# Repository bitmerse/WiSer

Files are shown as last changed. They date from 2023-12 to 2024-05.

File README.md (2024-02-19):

# WiSer

Experience seamless wireless serial connectivity with **WiSer**, a powerful set of two devices (**WiSer-USB** and **WiSer-TTL**) designed to facilitate a serial connection between your PC and embedded devices. Say goodbye to cumbersome USB cables and enjoy the freedom of wireless serial communication.



### Connection Diagram
WiSer-Connection

WiSer is a fully **Open Source** project. All hardware design files, firmware source code, and documentation are made available so you can inspect its inner workings. Our goal is to empower users, making it easy to program, understand, customize, and troubleshoot WiSer.

<p align="center">
  
</p>

# :file_folder: Repository contents
  - **/docs** - Documentation resources (Licensed under [CC BY-SA 4.0](docs/LICENSE))
  - **/hw** - Board design files (Licensed under [CERN-OHL-P-2.0](hw/LICENSE))
  - **/src** - Firmware source code (Licensed under [MIT](src/LICENSE))

# :blue_book: Documentation
  - [WiSer Product Page](https://bitmerse.com/products/wiser/)
  - [WiSer Quick Start Guide](https://bitmerse.gitbook.io/wiser-quick-start-guide/)
  - [WiSer Product Manual](https://bitmerse.gitbook.io/wiser-product-manual/)
  - [WiSer Specification](https://bitmerse.gitbook.io/wiser-product-spec-sheet/)

# :shopping_cart: Purchase Options
WiSer is currently available for purchase through the following platform:
 - [Crowd Supply](https://www.crowdsupply.com/bitmerse/wiser)

# :left_speech_bubble: Need Customization?
Do you need assistance customizing WiSer hardware or firmware to integrate into your product? Feel free to reach out to us via email below to explore and take advantage of our commercial services.
- e-mail: [contact@bitmerse.com](mailto:contact@bitmerse.com)
- website: [bitmerse.com](https://www.bitmerse.com)

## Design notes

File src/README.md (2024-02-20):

# WiSer Source Code

This directory contains the WiSer project source code built using the PlatformIO extension in VS Code.

## Compile and Upload

1. Press the "BOOT" button on WiSer-USB/WiSer-TTL and connect it to the USB connector on your computer.
2. After switching to boot mode, the board will accept the new firmware.
3. To build, click on the "Build" button in the PlatformIO toolbar at the bottom of the VS Code window.
4. To upload, click on the "Upload" button in the PlatformIO toolbar at the bottom of the VS Code window.
5. Verify that your code is compiled, uploaded, and executed on the WiSer board.

## Configuration MACROS

1. Before compilation, it is required to change the value of "DEVICE_CONFIG_MODE" to either "DEVICE_CONFIG_MODE_USB" for WiSer-USB or "DEVICE_CONFIG_MODE_UART" for WiSer-UART in `config.h`.
2. change the value of "CONFIG_ESPNOW_BROADCAST_ENABLE" to 1 to enable the brodcast mode in `config.h`. By default, broadcast mode is disabled.
3. change the value of "CONFIG_ESPNOW_ENCRYPTION_ENABLE" to 0 to disable the encryption of data in `config.h`. By default, encyption is enabled in th device.
4. Change the value of "CONFIG_ESPNOW_USE_NVS_PEER_MAC" to 0 in `config.h` to use the default peer MAC address stored in variable "s_app_peer_mac" in `app_espnow.c`. By default, device will use the pre-paired peer MAC address stored in the NVS memory during production.

### Notes

1. By default, WiSer devices are equipped with firmware that includes pre-paired devices, facilitating secure point-to-point wireless serial communication with data encryption enabled. Please be aware that the Broadcast mode is disabled by default.
2. `platformio.ini` contains your project settings. More information about this file can be found [here](https://docs.platformio.org/en/stable/projectconf/index.html).

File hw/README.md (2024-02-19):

# WiSer Hardware

This directory contains the hardware design files for WiSer-USB and WiSer-TTL, created using KiCad EDA.

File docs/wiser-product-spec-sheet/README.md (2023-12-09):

# WiSer

_Seamless plug-and-play solution for wireless serial connections_

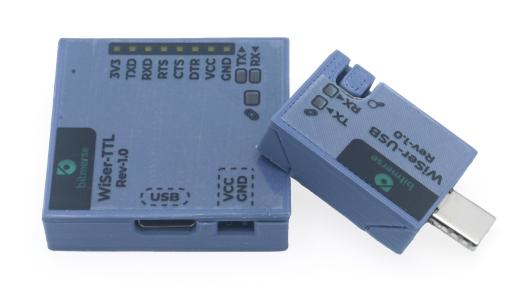
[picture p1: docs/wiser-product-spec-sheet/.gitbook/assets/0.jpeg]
<figure><figcaption></figcaption></figure>

Experience seamless wireless connectivity with WiSer, a device pair featuring WiSer-USB and WiSer-TTL. Simply plug WiSer-USB into your host system and WiSer-TTL into your embedded target device using dedicated UART pins. These devices establish a seamless peer-to-peer wireless connection over a 2.4 GHz Wi-Fi channel, functioning as a wireless serial bridge. Experience effortless communication between your host system and embedded target device over a wireless serial port.

To establish a wireless serial bridge between two host systems, employ a pair of WiSer-USB devices. These devices facilitate the creation of virtual serial ports on each host system, enabling seamless data communication between the host systems via the serial ports.

<table data-header-hidden><thead><tr><th width="327.3333333333333"></th><th width="62"></th><th></th></tr></thead><tbody><tr><td><strong>✔ Reliable</strong></td><td></td><td><strong>✔ Cross-platform</strong></td></tr><tr><td>A reliable solution for wireless connectivity to the serial port of your target device</td><td></td><td>Compatible with host systems running Windows, Linux, or Mac OS and also supports Android phones and tablets</td></tr><tr><td></td><td></td><td></td></tr><tr><td><strong>✔ Simple</strong></td><td></td><td><strong>✔ Open-source</strong></td></tr><tr><td>Plug-and-play convenience with no driver or software installation required</td><td></td><td>The product is entirely open-source, allowing easy modification and tinkering</td></tr></tbody></table>

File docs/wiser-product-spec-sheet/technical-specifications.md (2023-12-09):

# Technical Specifications

| | **WiSer-USB** | **WiSer-TTL** |
| --- | --- | --- |
| **Processing Unit** | Espressif Systems ESP32-S2 Wireless SoC | Espressif Systems ESP32-S2 Wireless SoC |
| **Wireless Protocol** | IEEE 802.11 b/g/n 2.4GHz | IEEE 802.11 b/g/n 2.4GHz |
| **Supported Platforms** | Windows, Linux, Mac and Android | - |
| **Serial Port** | <p><strong>Baud Rate:</strong> All standard and custom rates up to 921,600 baud</p><p><strong>Data bits:</strong> 6-bit, 7-bit, 8-bit</p><p><strong>Parity types:</strong> NONE, ODD, EVEN, MARK, and SPACE</p><p><strong>Stop bits:</strong> 1-bit, 1.5-bit, 2-bit</p><p><strong>Flow control:</strong> software (XON/XOFF), hardware (RTS/CTS), and None</p> | - |
| **User Indication** | 2 red LEDs for RX and TX indication | 3 red LEDs for RX, TX and CONN indication |
| **Buttons** | <p><strong>FIND-PAIR button:</strong> To locate the paired device</p><p><strong>BOOT button:</strong> for FW upgrade</p> | **BOOT button:** for FW upgrade |
| **Connectors** | **USB Type-C male plug:** For power supply, serial data communication and firmware upgrade | <p><strong>USB Type-C Female port:</strong> For Power supply and firmware upgrade</p><p><strong>Power supply Input Pins:</strong> To supply power using Jumper cables</p><p><strong>Serial Interface Pins:</strong></p><ul><li>3V3, TXD, RXD, RTS, CTS, DTR, VCC, GND</li></ul><p>(Note: 3V3 and VCC are power supply output pins which can be used to power external boards)</p> |
| **IO Pin tolerances** | - | <p><strong>Voltage range:</strong> 0 to 3.3V</p><p><strong>Output Pin Current:</strong> 25 mA</p><p><strong>Input Pin Current:</strong> 50nA</p> |
| **Power Supply** | 5V @ 500mA | 5V @ 500mA |
| **Antenna Type** | Omnidirectional chip antenna with 0.5 dBi gain (Peak) | Omnidirectional chip antenna with 0.5 dBi gain (Peak) |
| **Dimensions** | <p><strong>With enclosure:</strong> 37.8 x 20.4 x 8.2 mm</p><p><strong>Without enclosure:</strong> 35.8 x 14.4 x 4.7 mm</p> | <p><strong>With enclosure:</strong> 36.5 x 38.4 x 9.8 mm</p><p><strong>Without enclosure and header pins:</strong> 28 x 29 x 4.3 mm</p> |
| **Weight** | <p><strong>With enclosure:</strong> 4.5 grams</p><p><strong>Without enclosure:</strong> 1.6 grams</p> | <p><strong>With enclosure:</strong> 10.5 grams</p><p><strong>Without enclosure:</strong> 3.7 grams</p> |
| **Operating Temperature** | -40 to 85 °C | -40 to 85 °C |
| **Humidity** | < 60% RH (Non-condensing) | < 60% RH (Non-condensing) |

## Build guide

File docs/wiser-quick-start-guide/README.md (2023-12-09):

# Introduction

Welcome! This quick start guide will help you set up your WiSer devices and get started with wireless serial communication in no time.

WiSer is a hassle-free solution that requires no software installation, no drivers, and no complex setup procedures. WiSer device is supported with Windows 10 or higher, Mac, Linux, and Android OS.

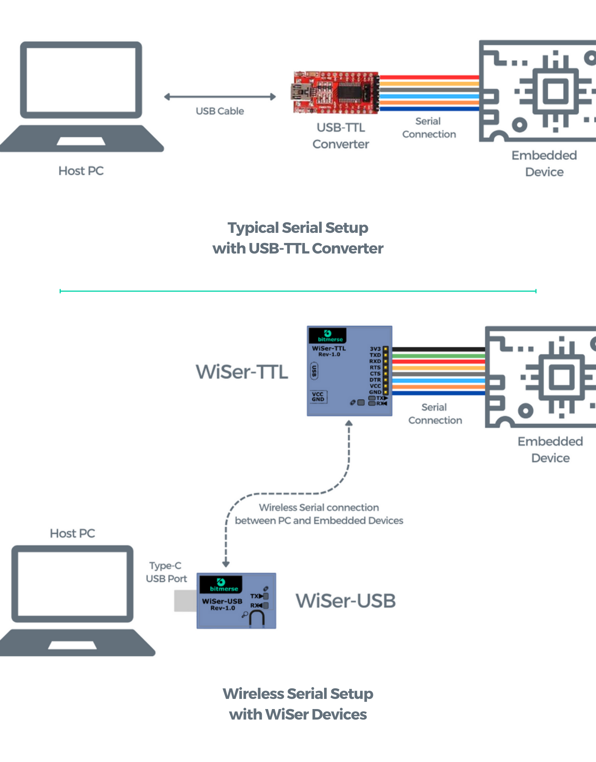
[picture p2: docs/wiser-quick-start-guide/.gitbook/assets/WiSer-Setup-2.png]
<figure><figcaption></figcaption></figure>

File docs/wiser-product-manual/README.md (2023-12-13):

# Introduction

### Introduction to WiSer 

Welcome! This user manual is your guide to setting up and using WiSer, the wireless serial device pair. WiSer provides seamless and hassle-free wireless communication between your PC and embedded devices. WiSer, short for “wireless serial device,” provides a cutting-edge alternative to traditional USB to TTL converters, offering an advanced and efficient means of UART communication.

We understand that connectivity requirements vary, which is why we offer multiple variants of WiSer. For those seeking wireless communication between two systems with only USB ports, our pair of WiSer-USB devices is the ideal solution.

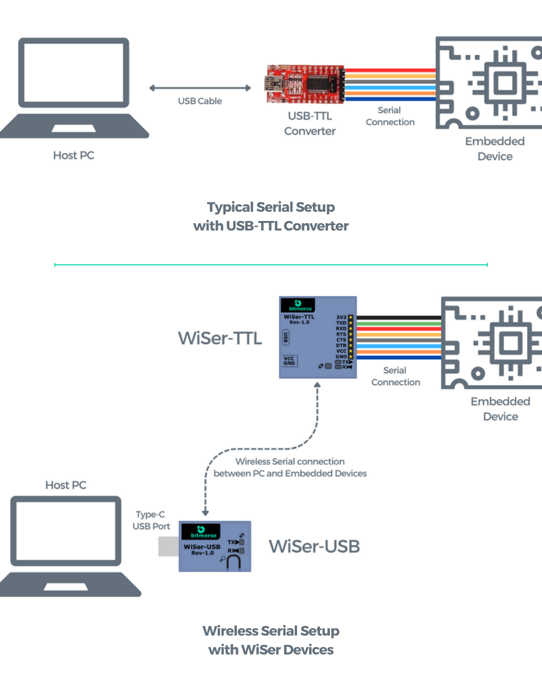
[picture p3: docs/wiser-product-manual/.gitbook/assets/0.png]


### Key Features 

* **Seamless Wireless Connectivity:** WiSer provides a reliable wireless connection, eliminating the limitations of traditional wired setups, and allowing you to move around while maintaining an uninterrupted connection. Connect your PC and embedded devices wirelessly for ultimate convenience.
* **Hassle-Free Setup:** WiSer's plug-and-play nature ensures a quick and effortless setup, saving you time and effort. **WiSer doesn’t require any software or driver installation.**
* **Reliable Cord-Free Serial Communication:** WiSer ensures stable and efficient wireless serial communication for various applications. Say goodbye to tangled cables and enjoy the freedom of wireless connectivity.
* **Secure Data Transfer:** WiSer ensures data protection using AES-CCMP encryption.
* **Complete Electrical Isolation:** WiSer provides full electrical isolation between your embedded device and PC, a distinctive feature absent in conventional USB-TTL converters.
* **Compatibility and Convenience:** Designed to be compatible with a wide range of devices and operating systems, WiSer offers versatility and ease of use.
* **High Performance:** WiSer delivers reliable and fast communication for tasks such as debugging, logging, firmware updates, and data transfer over the serial port.

### List of Potential applications using WiSer 

* **Internet of Things (IoT) Devices:** WiSer enables wireless communication between IoT devices and a PC, facilitating seamless data exchange and control.
* **Robotics/Drones:** WiSer can be utilized in robotic systems/Drones for wireless communication between the central control unit and various robotic components.
* **Embedded Systems:** WiSer simplifies the connection between embedded systems and a PC, allowing for wireless debugging, programming, and data transfer.
* **Home/Industrial Automation:** WiSer can be integrated into automation systems, enabling wireless communication between the central control unit and smart devices or sensors.
* **Automotive Electronics:** WiSer can be employed in automotive applications, allowing wireless communication between the vehicle's onboard systems and external devices for diagnostics, firmware updates, and more.
* **Wearable Devices:** WiSer provides a wireless communication solution for wearable devices, connecting them to a PC for data transfer, configuration, and firmware updates.
* **Electronic Prototyping:** WiSer simplifies the process of prototyping and testing electronic circuits by providing wireless communication between a development board and a PC, reducing the need for physical cables.
* **Remote Monitoring Systems:** WiSer facilitates wireless communication between remote monitoring systems and a central control station, enabling real-time data monitoring and control.
* **Educational Projects:** WiSer can be used in educational settings for teaching and learning about serial communication, embedded systems, and wireless technologies.

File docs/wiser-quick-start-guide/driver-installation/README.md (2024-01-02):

# Driver Installation

### No Drivers Required for WiSer 

WiSer is a hassle-free solution that requires no software installation, no drivers, and no complex setup procedures.

Supported platforms for WiSer device:

* Windows 10 or higher
* Mac
* Linux
* Android

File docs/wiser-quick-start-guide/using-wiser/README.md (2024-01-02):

# Using Wiser

WiSer simplifies the process of establishing wireless serial communication between your PC or device and embedded devices. Here, we'll walk you through the straightforward steps for effectively utilizing WiSer.

### WiSer Devices Connection Setup 

See the [WiSer Setup](../wiser-setup/) section for detailed information about the setup and powering up of the devices.

#### WiSer WS-UT-BM variant

Use this SKU variant for communication between your host system and embedded device as shown in the diagram below.

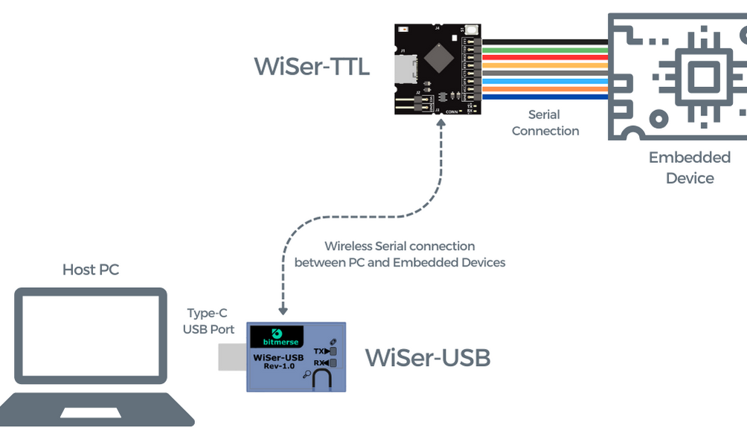
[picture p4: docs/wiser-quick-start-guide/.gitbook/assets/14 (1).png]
<figure><figcaption></figcaption></figure>

#### WiSer WS-UT-EN variant

Use this SKU variant for communication between your host system and embedded device as shown in the diagram below.

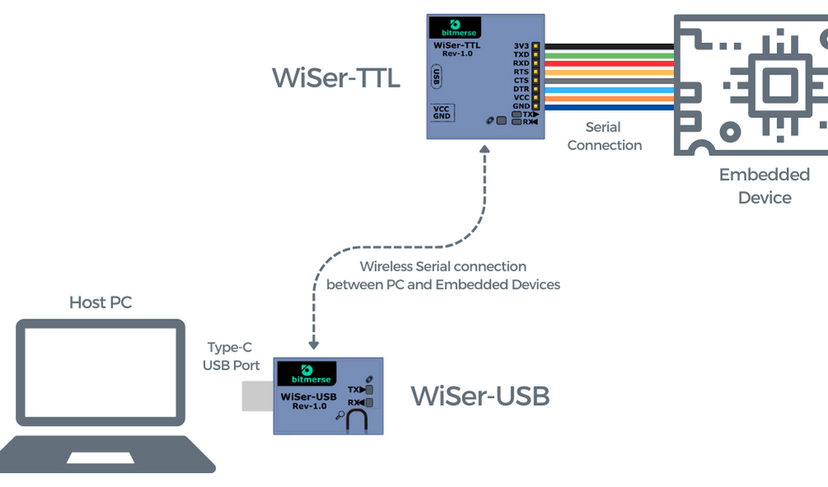
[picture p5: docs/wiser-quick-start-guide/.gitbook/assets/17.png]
<figure><figcaption></figcaption></figure>

#### WiSer WS-UU-EN variant 

Use this SKU variant for communication between 2 host systems as shown in the diagram below.

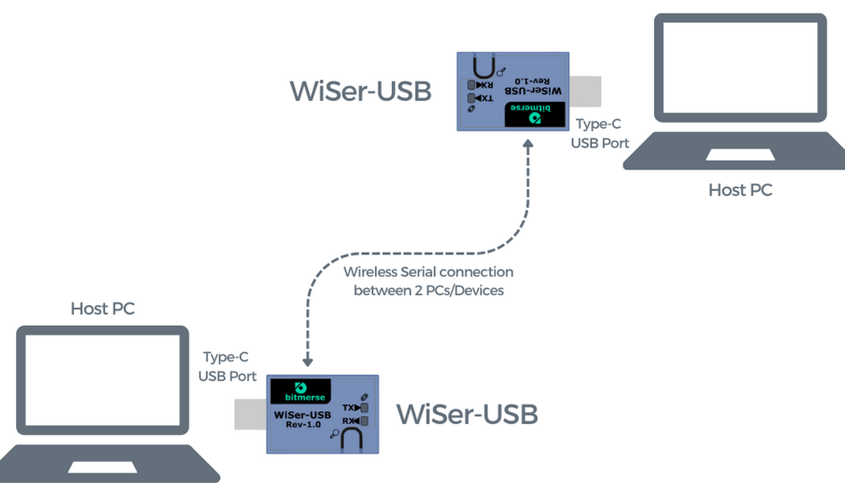
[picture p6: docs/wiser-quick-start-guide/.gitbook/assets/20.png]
<figure><figcaption></figcaption></figure>

### Accessing the Serial Port 

Once the WiSer devices are connected, a virtual serial port will be automatically generated on your PC. Verify serial port in the Device Manager of your PC. You can access it through your preferred terminal software or even any custom software you've developed.

* Following example image shows the WiSer device detected in Device manager of Windows 10 PC

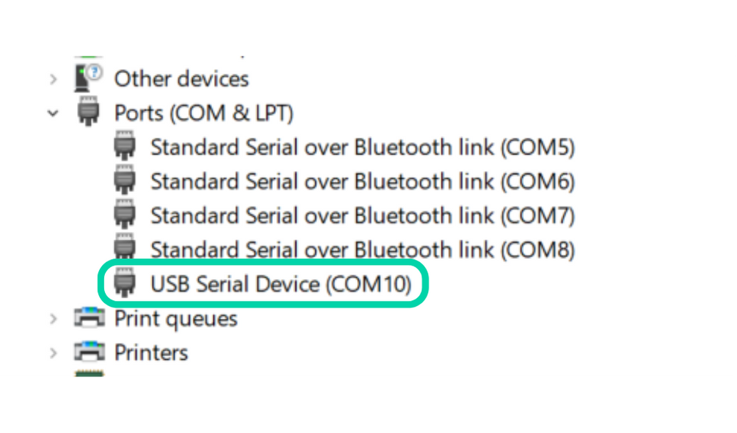
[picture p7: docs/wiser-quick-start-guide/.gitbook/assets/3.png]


* Following example image shows the serial port selection in TeraTerm serial tool.

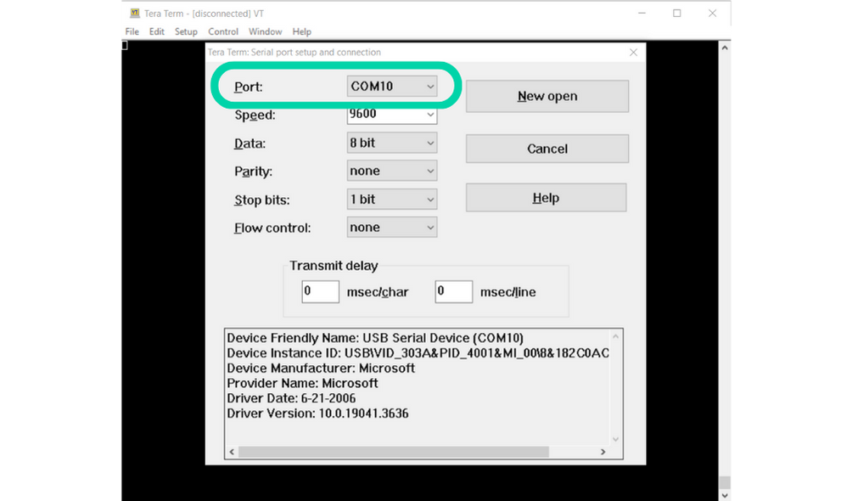
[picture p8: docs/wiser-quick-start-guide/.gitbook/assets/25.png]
<figure><figcaption></figcaption></figure>

### Baud Rate Configuration 

WiSer accommodates various baud rates to meet your communication requirements, whether they are standard or non-standard, with a maximum speed of 921,600 baud. Baud rate configuration can be conveniently adjusted within your terminal software.

By confirming that both the host system and the embedded device share the same baud rate, you can guarantee the successful transmission and reception of data in your wireless serial communication setup.

**Supported baud rates:** all standard and custom rates up to 921,600 baud

* Following example image shows the Baud rate configuration in TeraTerm serial tool.

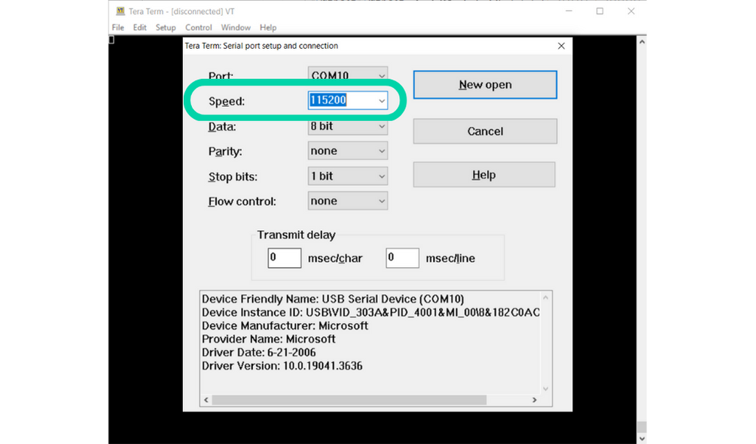
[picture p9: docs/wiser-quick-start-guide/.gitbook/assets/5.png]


### Flow Control Options 

WiSer is equipped with hardware flow control, specifically RTS/CTS, ensuring a dependable data transmission process. To align with your application's requirements, configure your terminal software to integrate flow control. To activate RTS/CTS hardware flow control, press and hold the 'Find Pair' button for more than 2 seconds. This action triggers fast flashing of the CONN LED for 5 seconds, indicating the enabled status. Similarly, a prolonged press on the 'Find Pair' button for more than 2 seconds deactivates the RTS/CTS flow control, signaled by slow flashing of the CONN LED for 5 seconds. It's important to note that flow control is not supported for the WiSer WS-UU-EN variant.

**Supported flow control:** software (XON/XOFF), hardware (RTS/CTS), and None

* Following example image shows the flow control selection in TeraTerm serial tool.

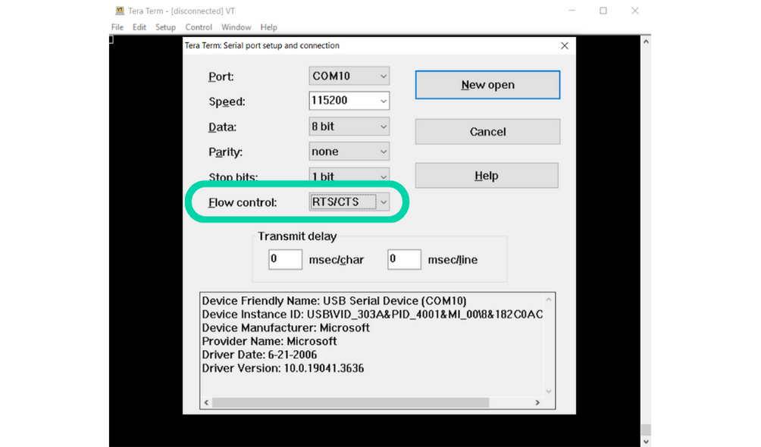
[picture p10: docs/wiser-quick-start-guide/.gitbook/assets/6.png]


### DTR Control Signal 

WiSer also provides the DTR (Data Terminal Ready) control signal, which is crucial for call control in devices like data modems. It signifies that the terminal is prepared for communication. If your target embedded device supports DTR signal, then connect WiSer-TTL’s DTR to your target device and control it using your favorite serial terminal software or custom application. DTR control signal is not supported for WiSer WS-UU-EN variant.

* Following example image shows DTR configuration in Teraterm serial tool.

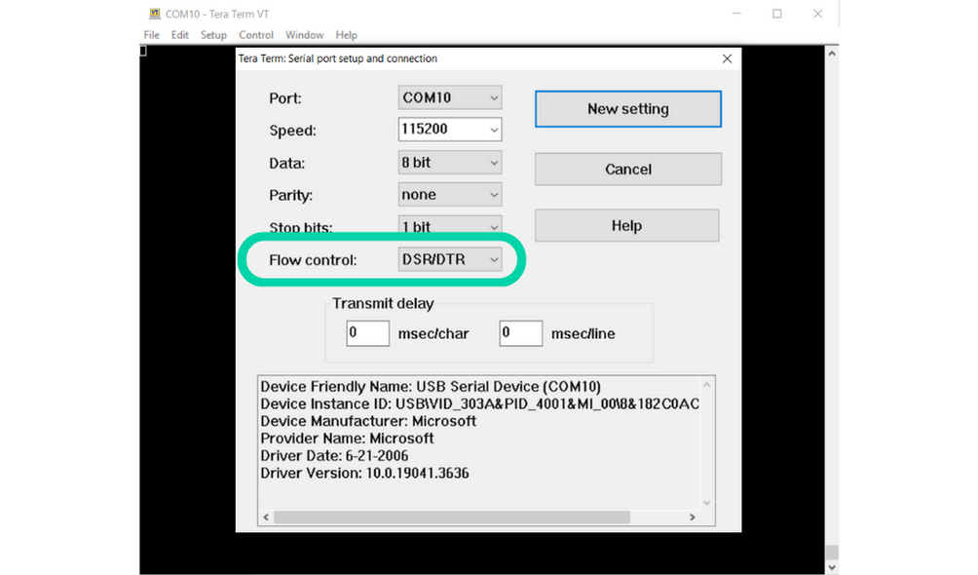
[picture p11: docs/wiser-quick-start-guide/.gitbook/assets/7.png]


### Data bit, Parity, and Stop bits

WiSer provides configuring Data Bit, Parity Type, and Stop Bits settings from your favorite serial terminal software or custom application.

**Supported data bits:** 6-bit, 7-bit, 8-bit

**Supported parity types:** NONE, ODD, EVEN, MARK, and SPACE

**Supported stop bits:** 1-bit, 1.5-bit, 2-bit

* Following example image shows Data Bit, Parity Type, and Stop Bit settings in TeraTerm serial tool.

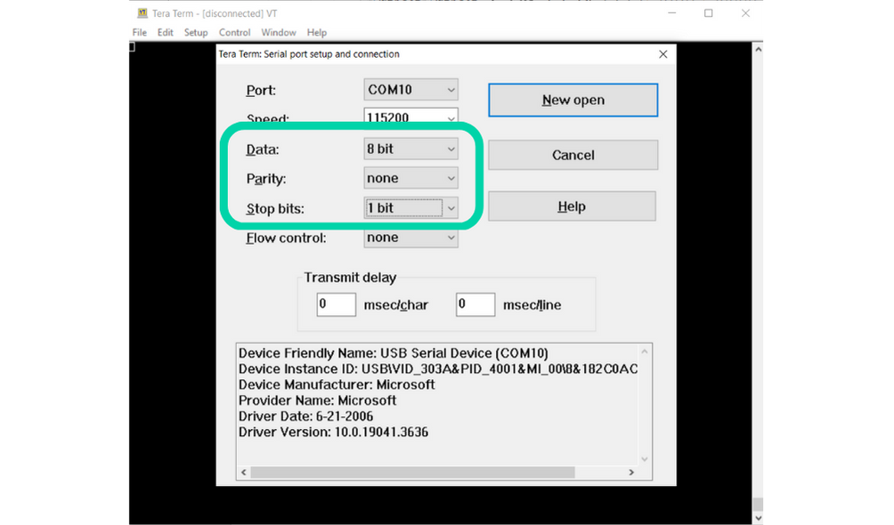
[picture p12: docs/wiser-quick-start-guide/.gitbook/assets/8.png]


### Initiating Serial Communication 

You can now commence serial communication between your PC and the embedded device. For specific communication settings, please consult the user manual of your embedded device.

Ensure that the serial port settings align with those of your target embedded device, then open WiSer's serial port in your favorite serial terminal software or custom application to initiate communication.

* Following example image shows TeraTerm serial port setup window. To open the Serial port, click on “New Open” button.

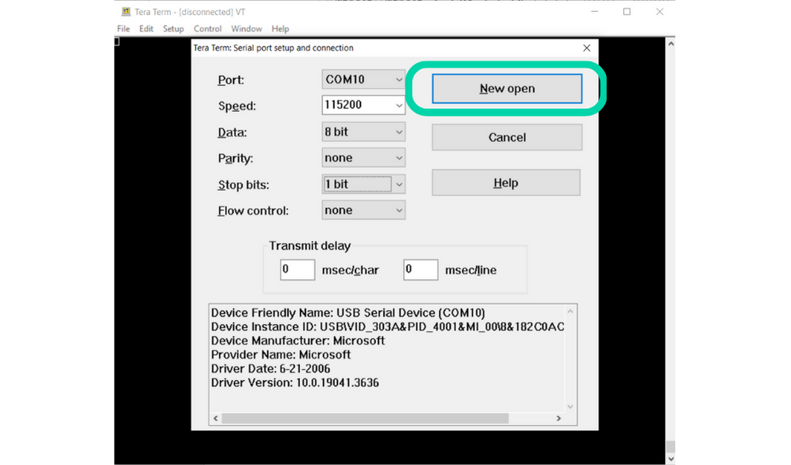
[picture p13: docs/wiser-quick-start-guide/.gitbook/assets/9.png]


* Following example image shows TeraTerm serial terminal with an opened selected serial port and configuration.

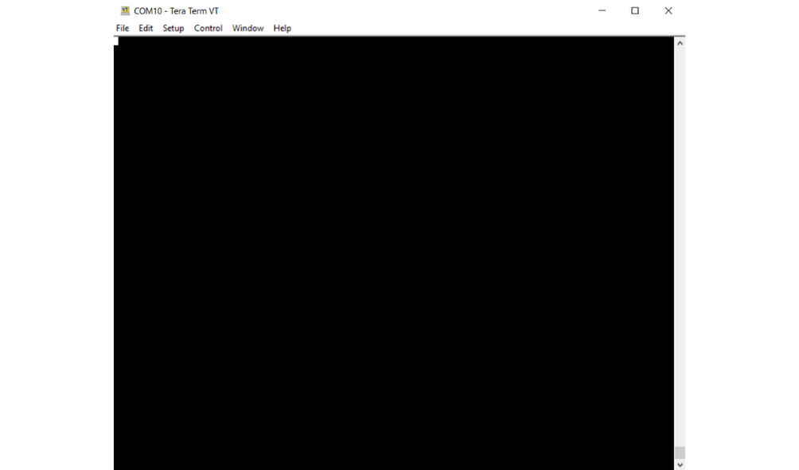
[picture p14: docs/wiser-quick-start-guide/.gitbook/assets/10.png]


#### WiSer WS-UT-BM/EN variant 

* Following image demonstrates the setup of WiSer devices with host system and Raspberry Pi (Embedded Device)

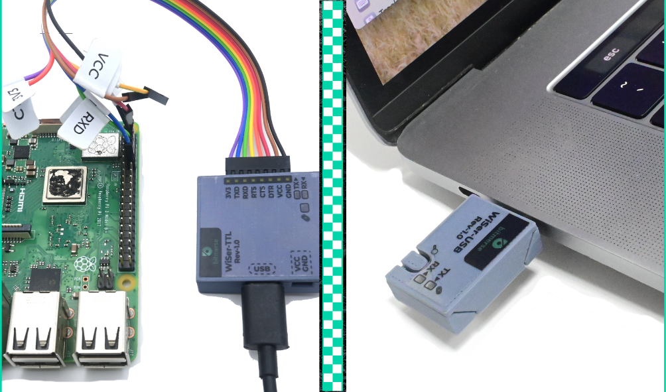
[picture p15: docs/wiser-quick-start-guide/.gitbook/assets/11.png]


* Following image demonstrates the communication between host system and Raspberry PI. It shows wireless access to debug UART terminal of Raspberry PI using WiSer devices.

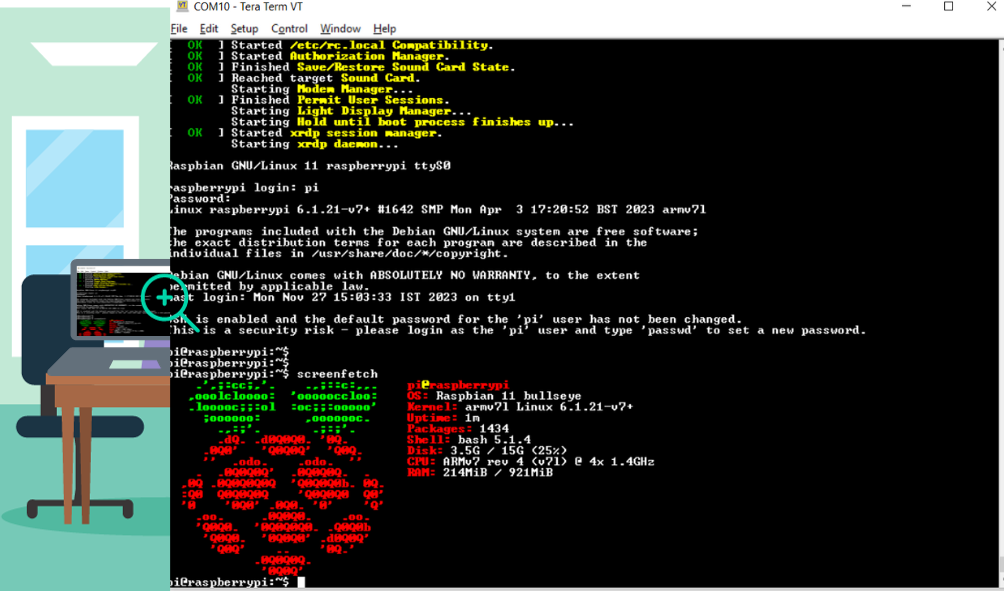
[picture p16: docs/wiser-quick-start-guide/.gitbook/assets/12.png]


* Following image demonstrates the communication between Android Tablet and Raspberry PI. It shows wireless access to debug UART terminal of Raspberry PI on Android device using WiSer devices.

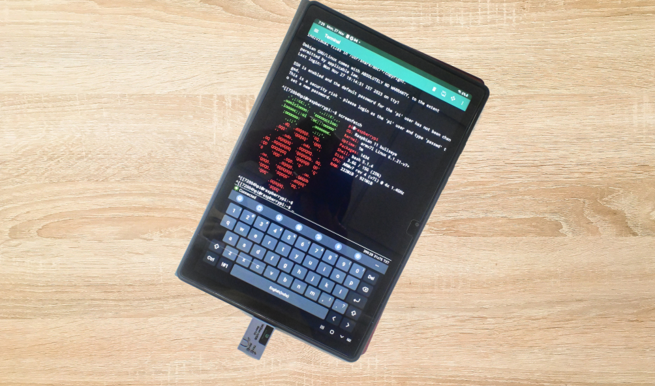
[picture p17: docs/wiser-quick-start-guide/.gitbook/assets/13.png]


#### WiSer WS-UU-EN variant 

* Following image demonstrates 2 host systems communicating wirelessly using WiSer devices. It shows serial terminal of Host PC-1 and Host PC-2.

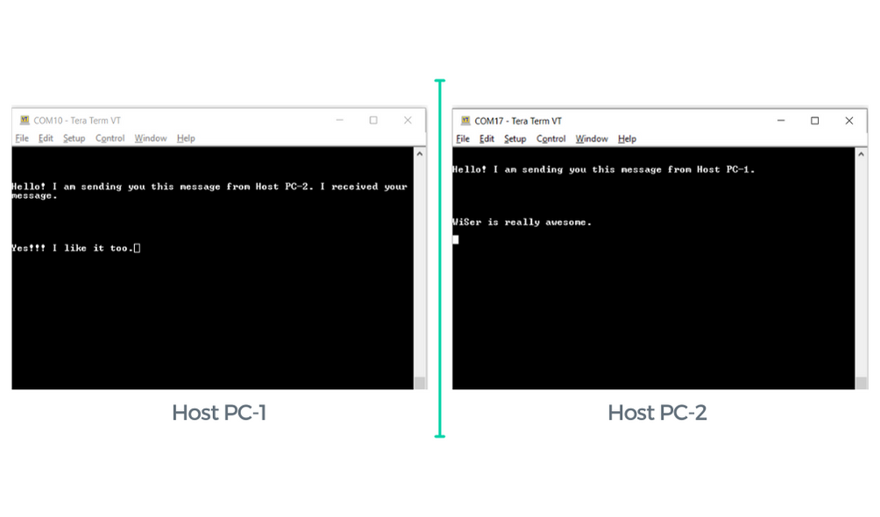
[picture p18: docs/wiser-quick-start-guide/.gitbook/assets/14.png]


By following these steps, you can seamlessly set up and utilize the WiSer device for wireless serial communication. Whether you're working on IoT projects, industrial automation, data logging, or any application that relies on serial communication, WiSer streamlines the process, offering cord-free convenience and efficient data exchange.

For specific instructions on configuring your particular terminal software, please refer to the respective software's user manual.

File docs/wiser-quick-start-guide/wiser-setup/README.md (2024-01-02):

# WiSer Setup

### WiSer Devices connection setup 

#### WS-UT-BM Variant 

**Connecting WiSer-USB**

* Locate the WiSer-USB device in WiSer kit.
* Connect the WiSer-USB device to an available USB port on your PC.

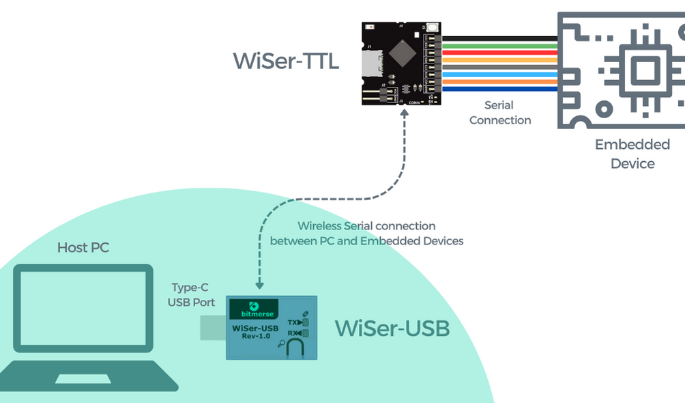
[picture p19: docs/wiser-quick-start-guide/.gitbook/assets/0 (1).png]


**Connecting WiSer-TTL**

* Locate the WiSer-TTL device in WiSer kit.
* Connect the WiSer-TTL device to the serial interface of your embedded device using jumper cable. You also have the flexibility to connect the device to your embedded system using castellated pins positioned at the edge of the board.

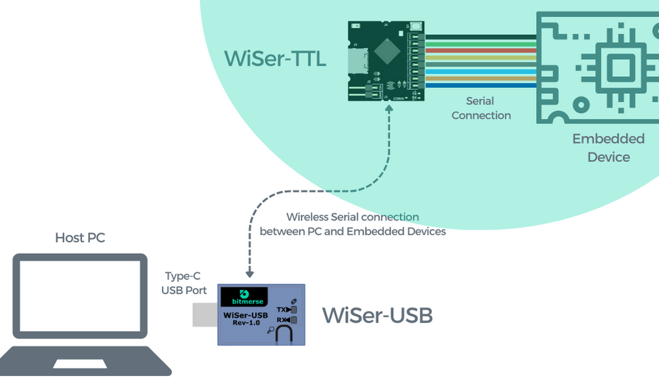
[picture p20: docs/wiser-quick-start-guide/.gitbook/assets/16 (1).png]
<figure><figcaption></figcaption></figure>

#### WS-UT-EN Variant

**Connecting WiSer-USB**

* Locate the WiSer-USB device in WiSer kit.
* Connect the WiSer-USB device to an available USB port on your PC.

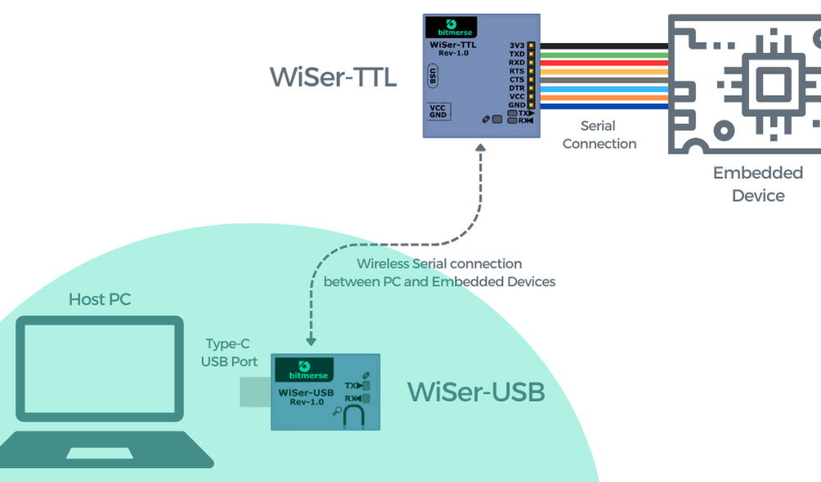
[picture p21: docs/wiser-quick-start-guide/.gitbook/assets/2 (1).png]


**Connecting WiSer-TTL**

* Locate the WiSer-TTL device in WiSer kit.
* Connect the WiSer-TTL device to the serial interface of your embedded device using jumper cable.

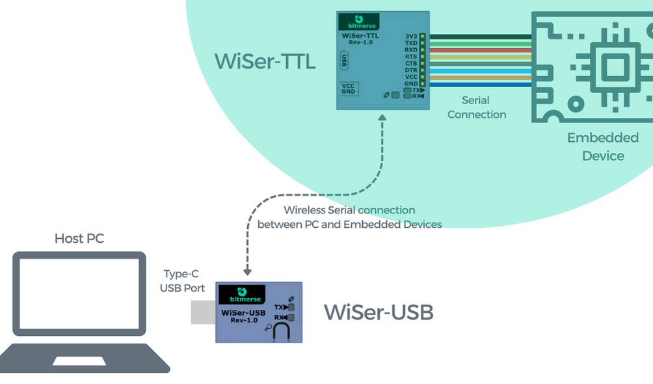
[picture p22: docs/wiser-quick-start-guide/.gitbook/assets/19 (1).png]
<figure><figcaption></figcaption></figure>

#### WS-UU-EN Variant 

**Connecting WiSer-USB**

* Locate the 2 WiSer-USB devices in WiSer kit.
* Connect one WiSer-USB device to an available USB port on your PC/system and another WiSer-USB device to another host system.

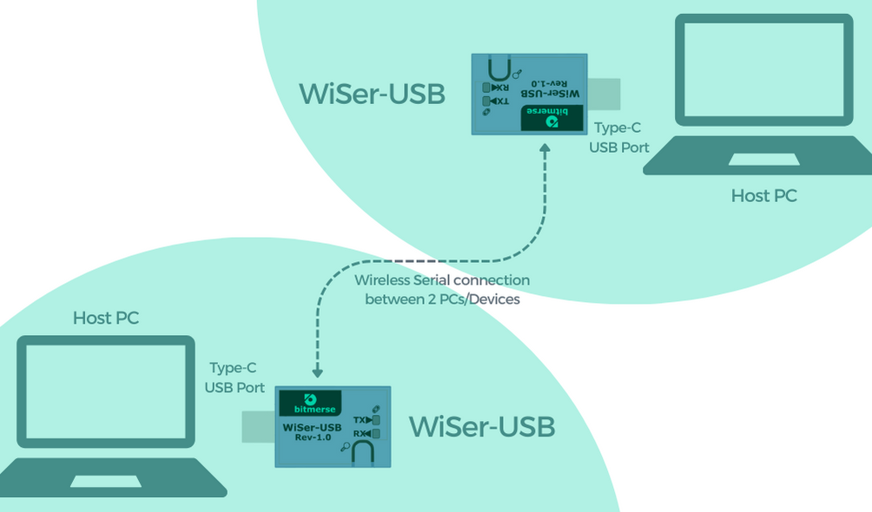
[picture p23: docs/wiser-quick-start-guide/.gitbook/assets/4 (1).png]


### Powering On the Devices 

#### WiSer-USB 

There is only 1 way to provide power to the WiSer-USB board:

* Type-C USB port (Male) plug, default power supply (Directly connects to the Type-C port of host system)

#### WiSer-TTL

There are three mutually exclusive ways to provide power to the WiSer-TTL board:

* Type-C USB port (Female) connector, default power supply (The power can be supplied through a power adapter, power bank, or even from the host system itself)
* Through the header pins (J2), where you can connect to the VCC (+5V) and GND pins.
* Via the castellated pins (J3), where you can provide power by connecting to the VCC (+5V) and GND pins.

This versatility in powering options allows you to choose the method that best suits your setup and project requirements.

### LED Indicators 

WiSer devices are equipped with LED status indicators to convey essential information.

#### Rx and Tx LED 

These LEDs illuminate when active serial communication is established between devices, providing visual confirmation of data transfer.

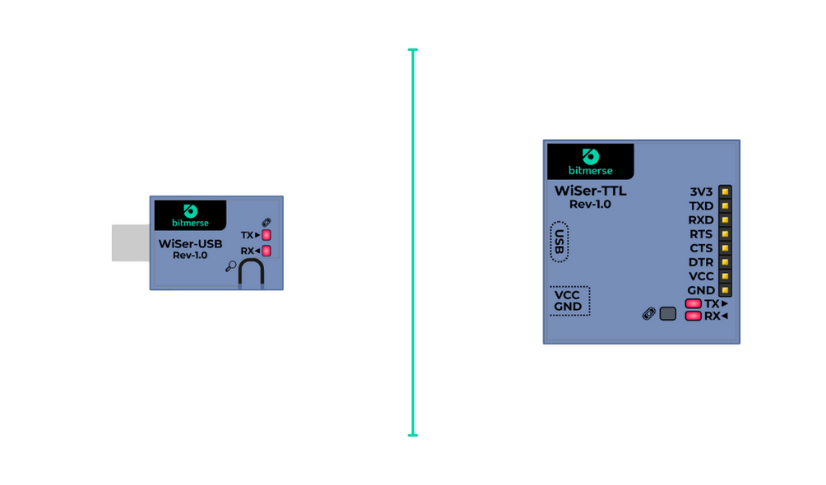
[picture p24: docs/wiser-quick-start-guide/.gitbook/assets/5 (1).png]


#### CONN LED 

This LED activates when you press the 'Find Pair' button on the WiSer-USB device.

**CONN LED Indications:**

* **Steady ON for 5 Seconds:** A short press of the 'Find Pair' button initiates this event. Both paired WiSer devices turn ON the CONN LED for 5 seconds, aiding in identifying the paired device when multiple WiSer device pairs are in use.
* **Flashing FAST for 5 Seconds:** Press and hold the 'Find Pair' button for more than 2 seconds to trigger this event. Both paired devices rapidly flash the CONN LED for 5 seconds, signifying that the RTS/CTS hardware flow control is now enabled. In this mode, the ESP32-S2 chip on WiSer-TTL utilizes the RTS and CTS pins for hardware flow control.
* **Flashing SLOW for 5 Seconds:** Another long press of the 'Find Pair' button for more than 2 seconds triggers this event. Both paired devices slowly flash the CONN LED for 5 seconds, indicating that the RTS/CTS hardware flow control is now disabled. In this mode, the RTS and DTR pins can serve as general-purpose I/Os, controllable via USB requests from the host system.

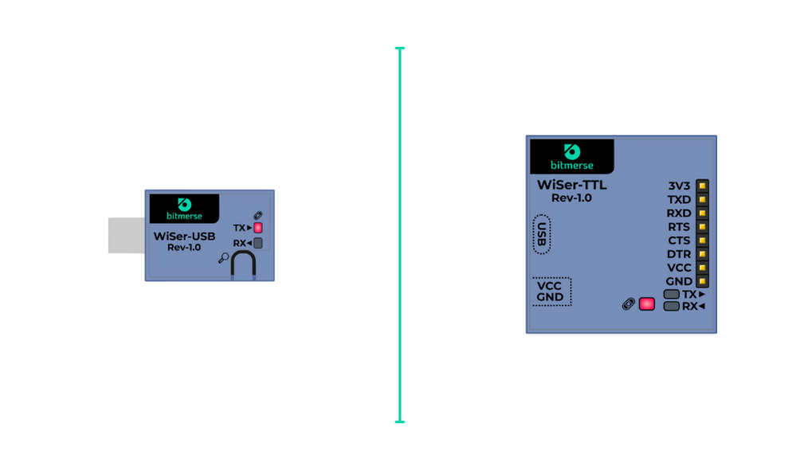
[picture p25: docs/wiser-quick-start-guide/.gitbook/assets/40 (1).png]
<figure><figcaption></figcaption></figure>

These LED indicators serve as your visual guides throughout the setup process, ensuring that you have the necessary feedback to facilitate a seamless connection.

Please note that for the WiSer-USB device, the CONN LED is combined with the Tx (Transmit) LED. This means that when you press ‘Find Pair’ button or transmit data, the same LED will provide feedback for both functions.

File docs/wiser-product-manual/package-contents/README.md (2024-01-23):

# Package Contents

WiSer offers different package variants to suit your specific needs. Please review the table below to understand the package contents for each SKU variant:

| **SKU Variant** | <p><strong>WiSer-USB Device</strong><br><strong>(with Enclosure)</strong></p> | <p><strong>WiSer-TTL Device</strong><br><strong>(without Enclosure)</strong></p> | <p><strong>WiSer-TTL Device</strong><br><strong>(with Enclosure)</strong></p> | **Description** |
| --- | --- | --- | --- | --- |
| **WS-UT-BM** | ✔ | ✔ | | It comes with one WiSer-USB device and one WiSer-TTL device with loose header pins (Not mounted). It's suitable for mounting the WiSer-TTL on your own PCB. |
| **WS-UT-EN** | ✔ | | ✔ | It comes with one WiSer-USB device and one WiSer-TTL device with header pins mounted and also includes Enclosure. It's suitable for connecting the target device using jumper cables. |
| **WS-UU-EN** | ✔ | | | It comes with two WiSer-USB devices. It's suitable for creating a serial port connection between two host systems. |

Select the package variant that best fits your project/product requirements. If you have any questions about the package contents or need assistance, please feel free to [reach out to our customer support team.](mailto:support@bitmerse.com)

### What's Included 

Your selected WiSer SKU Variant includes the following components:

#### WS-UT-BM Variant 

* WiSer-USB Device with Enclosure
* WiSer-TTL Device
* USB Power Cable for WiSer-TTL
* loose header pins (Not mounted)
* Jumper Cables
* Quick Start Guide

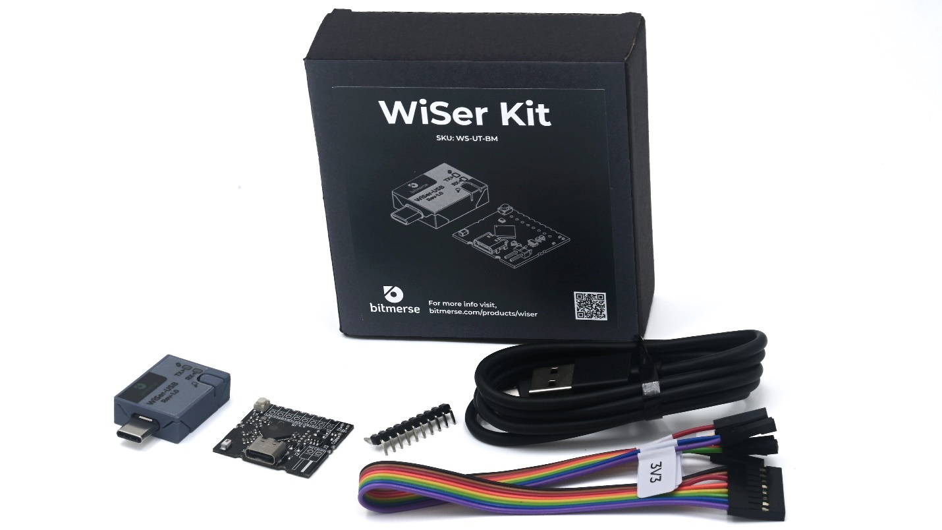
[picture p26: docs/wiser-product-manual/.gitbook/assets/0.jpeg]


#### WS-UT-EN Variant 

* WiSer-USB Device with Enclosure
* WiSer-TTL Device with Enclosure (with header pins mounted)
* USB Power Cable for WiSer-TTL
* Jumper Cables
* Quick Start Guide

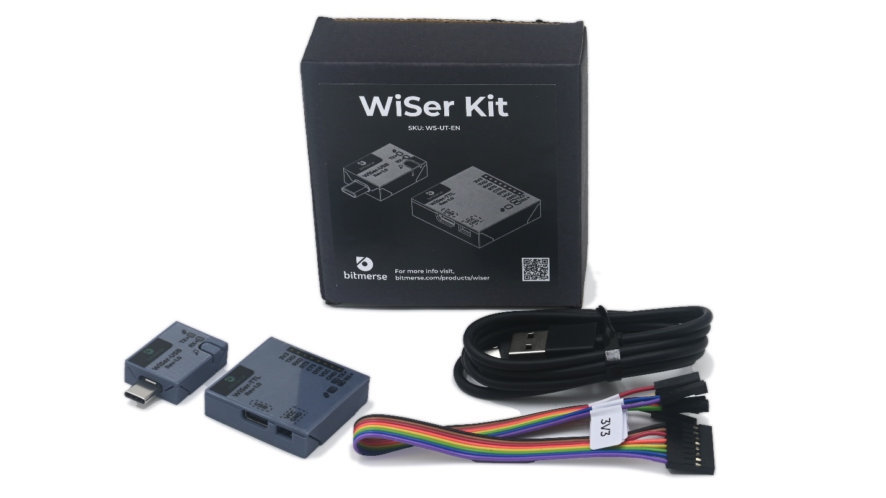
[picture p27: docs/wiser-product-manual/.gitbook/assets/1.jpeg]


#### WS-UU-EN Variant 

* 2 WiSer-USB Devices with Enclosure
* Quick Start Guide

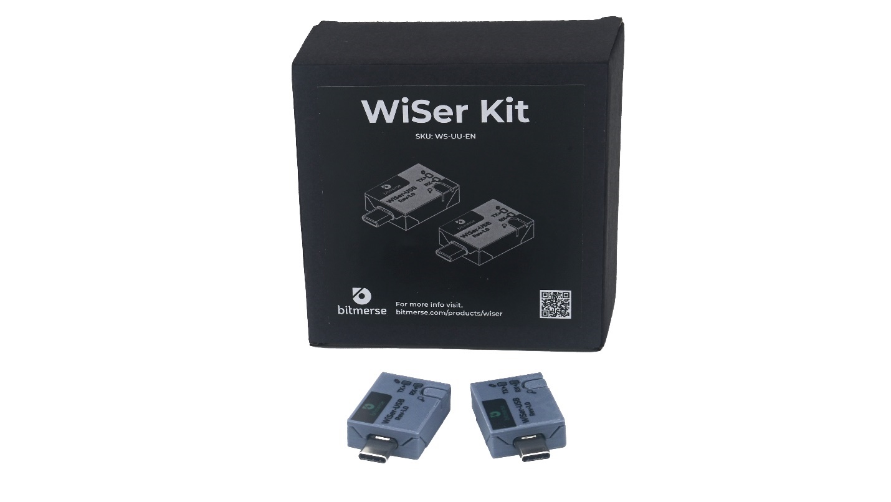
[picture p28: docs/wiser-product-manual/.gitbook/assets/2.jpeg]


Ensure that all items are present in your package before proceeding.

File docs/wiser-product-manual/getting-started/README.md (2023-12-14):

# Getting Started

### Device Overview 

Before setting up WiSer, let's familiarize ourselves with the devices:

#### WiSer-USB 

**Functional Description**

This device connects to your PC/System. Upon powering up, the WiSer-USB creates a virtual serial port on the host system and waits for its paired WiSer device to power up as well.

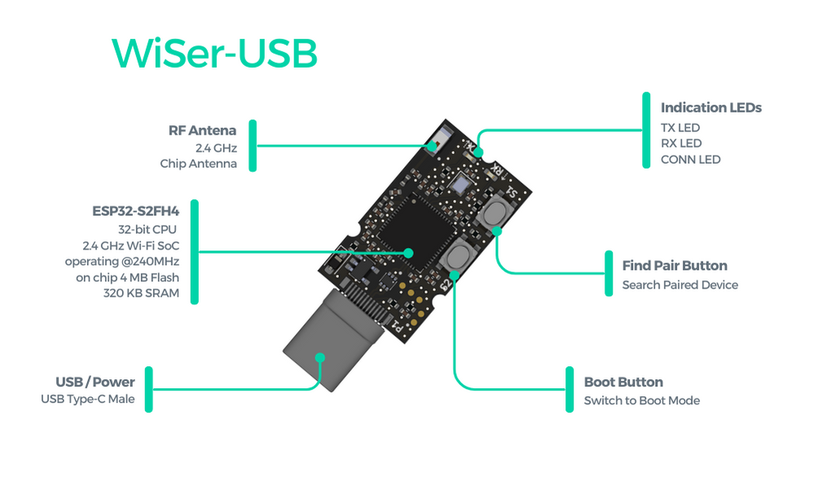
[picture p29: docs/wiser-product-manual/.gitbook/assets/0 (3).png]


The WiSer-USB device is factory-paired with either a WiSer-TTL or another WiSer-USB device, depending on the product variant (as indicated in SKU Variant Table). Once both the WiSer-USB and the paired device are powered up, they automatically establish a connection.

The **‘Find Pair'** button on WiSer serves a multi-functional role, facilitating the identification and configuration of paired devices:

1. **Short Press:** Initiates the identification event. When you briefly press the 'Find Pair' button, the CONN LED on both paired WiSer devices remains steadily ON for 5 seconds. This helps users identify the specific paired devices, particularly useful when managing multiple WiSer device pairs.
2. **Long Press (More than 2 Seconds):**

* **Flashing FAST:** A prolonged press triggers the RTS/CTS hardware flow control activation. Both paired devices respond by rapidly flashing the CONN LED for 5 seconds, indicating that the hardware flow control is now enabled. In this mode, the ESP32-S2 chip on WiSer-TTL utilizes the RTS and CTS pins for hardware flow control.
* **Flashing SLOW:** Another long press deactivates the RTS/CTS hardware flow control. In response, both paired devices exhibit a slow flash of the CONN LED for 5 seconds, signaling that the hardware flow control is now disabled. In this mode, the RTS and DTR pins can serve as general-purpose I/Os, controllable via USB requests from the host system.

In summary, the 'Find Pair' button provides a convenient way to manage and identify paired WiSer devices, as well as to toggle the RTS/CTS hardware flow control functionality based on the duration of the button press. Upon initial power-up, the WiSer device has **hardware flow control deactivated by default.**

The **‘Boot button’** serves the purpose of flashing firmware on the ESP32-S2 chip within the WiSer-USB device.

Once the connection is established, users can engage in serial communication by using applications such as PuTTY, TeraTerm, or any other software that operates through a serial port.

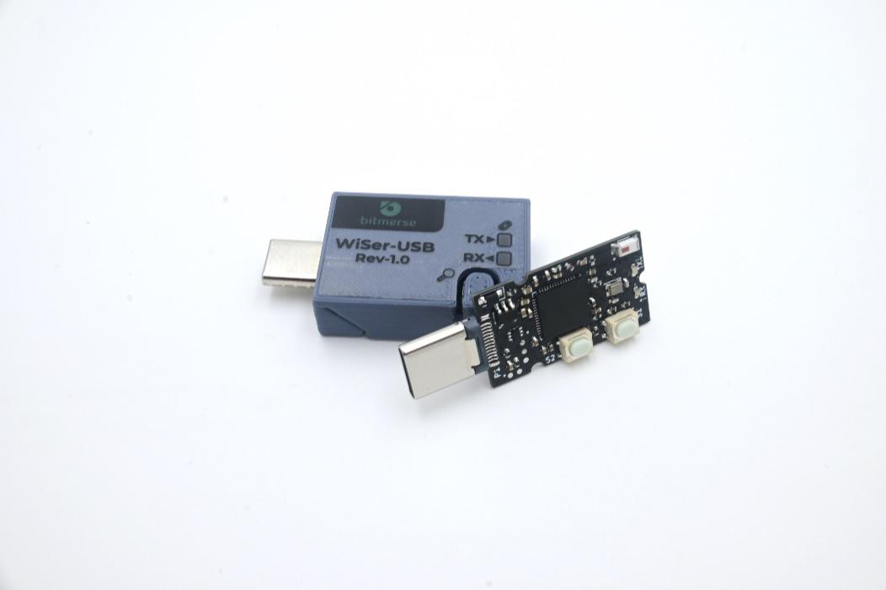
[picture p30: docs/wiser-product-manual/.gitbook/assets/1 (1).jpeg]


Notably, the WiSer-USB device supports a wide range of baud rates, whether standard or non-standard, with a maximum speed of 921,600 baud. Any changes to the baud rate in your application will be automatically synchronized with the paired device.

| **Key Component** | **Description** |
| --- | --- |
| ESP32-S2FH4 | A MCU with ESP32-S2 at its core. For more information, see [ESP32-S2 Datasheet](https://www.espressif.com/sites/default/files/documentation/esp32-s2\_datasheet\_en.pdf). |
| S1 | Find Pair button. Short press the button to identify the paired WiSer-USB or WiSer-TTL device. Long press the button for 2 seconds to toggle the RTS/CTS hardware flow control. |
| S2 | Boot button. Holding down the button and power on the board to switch into boot mode and flash new firmware. Note: Flashing new firmware will erase the WiSer firmware. |
| P1 | Type-C USB Port (Male) plug. Power supply for the board as well as the communication interface between a computer and the ESP32-S2 MCU. |
| TX/CONN LED | Reflects the transmit data on serial interface. Turns ON for 5 seconds when user presses the ‘Find Pair’ button for more than 1 second. |
| RX LED | Reflects the received data on serial interface. |

**Power Supply Options**

There is only 1 way to provide power to the WiSer-USB board:

* Type-C USB port (Male) plug, default power supply (Directly connects to the Type-C port of host system)

#### WiSer-TTL 

**Functional Description**

The WiSer-TTL device connects to your embedded device for wireless communication. Upon power-up, the WiSer-TTL will establish a connection with its paired WiSer-USB device.

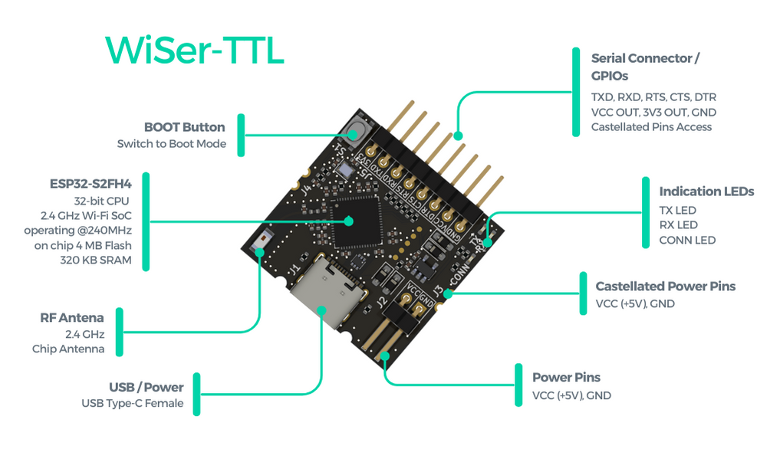
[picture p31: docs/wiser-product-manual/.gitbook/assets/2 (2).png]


The **‘Boot button’** serves the purpose of flashing firmware on the ESP32-S2 chip within the WiSer-TTL device.

The WiSer-TTL device is available in different variants. You can choose between variant with header pins pre-mounted or variant with loose header pins. This flexibility allows you to select the option that best suits your project requirements.

If you opt for the variant with header pins pre-mounted, you can effortlessly connect the WiSer-TTL device to your target device using jumper cables. On the other hand, if you choose the variant without header pins, you have the flexibility to solder it directly onto your embedded device's PCB, ensuring a secure and integrated connection. This adaptability allows you to tailor the setup to your specific project requirements, making the WiSer-TTL device a versatile choice for various applications.

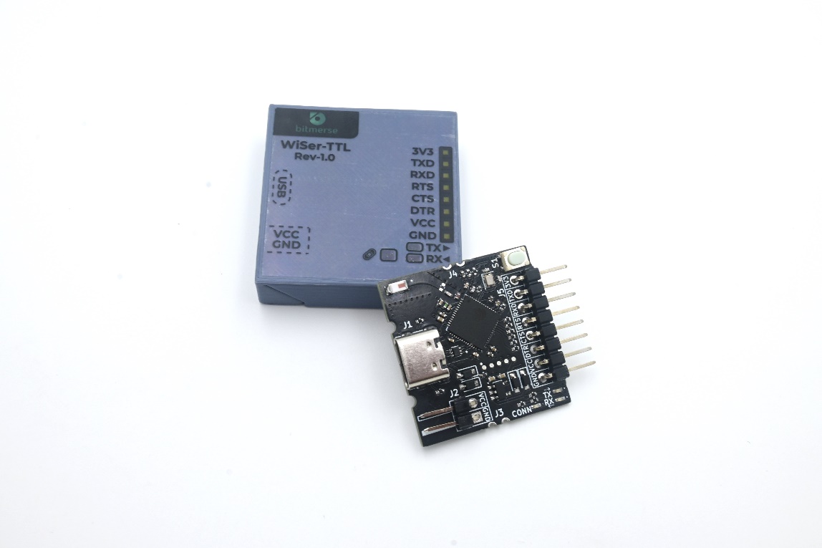
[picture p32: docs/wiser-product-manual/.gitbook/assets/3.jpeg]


You can use WiSer-TTL as ESP32-S2 development board as well and you can even integrate this small-sized board easily with PCB of your product.

| **Key Component** | **Description** |
| --- | --- |
| ESP32-S2FH4 | A MCU with ESP32-S2 at its core. For more information, see [ESP32-S2 Datasheet](https://www.espressif.com/sites/default/files/documentation/esp32-s2\_datasheet\_en.pdf). |
| S1 | Boot button. Holding down the button and power on the board to switch into boot mode and flash new firmware. Note: Flashing new firmware will erase the WiSer firmware. |
| J1 | Type-C USB Port (Female) connector. Power supply for the board as well as the communication interface between a computer and the ESP32-S2 MCU. |
| J2 | Header pins for power supply. VCC (+5V) and GND. |
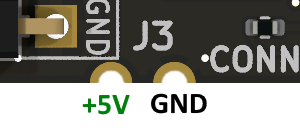
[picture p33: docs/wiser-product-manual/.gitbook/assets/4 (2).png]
| J3 | <p>The castellated Power pins.</p> |
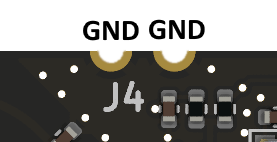
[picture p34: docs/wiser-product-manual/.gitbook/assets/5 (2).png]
| J4 | <p>The castellated Ground pins.</p> |
| TX LED | Reflects the transmit data on serial interface. |
| RX LED | Reflects the received data on serial interface. |
| CONN LED | Turns ON for 5 seconds when user presses the ‘Find Pair’ button for more than 1 second. |
| <p>I/O Header pins<br>(J5)</p> | The pins of ESP32-S2 MCU required for serial interface are broken out to the pin header on the board. |

**Header Block**

The table below provides the Name and Function of I/O header pins on connector J5 on the WiSer-TTL board.

| **No.** | **Name** | **GPIO** | **Function** |
| --- | --- | --- | --- |
| 1 | GND | - | Ground. |
| 2 | VCC | - | +5V output pin. |
| 3 | DTR | GPIO34 | UART DTR pin. (3.3V tolerant I/O) |
| 4 | CTS | GPIO35 | <p>UART CTS pin. (3.3V tolerant I/O)</p><p>Connect this pin to target device only if the RTS/CTS hardware flow control is enabled on target device.</p><p><strong>Note:</strong> Keep this pin NC (not connected) if hardware RTS/CTS hardware flow controller is disabled on target device.</p> |
| 5 | RTS | GPIO36 | <p>UART RTS pin. (3.3V tolerant I/O)</p><p>Connect this pin to target device only if the RTS/CTS hardware flow control is enabled on target device.</p><p><strong>Note:</strong> Keep this pin NC (not connected) if hardware RTS/CTS hardware flow controller is disabled on target device.</p> |
| 6 | RXD | GPIO37 | UART RX pin (3.3V tolerant I/O) |
| 7 | TXD | GPIO38 | UART TX pin (3.3V tolerant I/O) |
| 8 | 3V3 | - | +3.3V output pin |

**Power Supply Options**

There are three mutually exclusive ways to provide power to the WiSer-TTL board:

* Type-C USB port (Female) connector, default power supply (The power can be supplied through a power adapter, power bank, or even from the host system itself)
* Through the header pins (J2), where you can connect to the VCC (+5V) and GND pins.
* Via the castellated pins (J3), where you can establish power by connecting to the VCC (+5V) and GND pins.

### System Requirements 

#### WS-UT-BM/EN Variant 

To use WiSer WS-UT-BM/EN, you'll need:

* A PC/Device with a USB port (Windows 10 or higher / Mac / Linux / Android OS)
* An embedded device with a compatible serial interface

#### WS-UT-BM/EN Variant 

To use WiSer WS-UU-EN, you'll need:

* 2 PCs/Devices with a USB port (Windows 10 or higher / Mac / Linux / Android OS)

Please check the specific requirements for your embedded device in the user manual of the respective device.

### Safety Precautions 

* Avoid exposure to extreme temperatures and humidity.
* Handle WiSer devices with care, avoiding impact and physical damage.
* Keep WiSer devices away from liquids and moisture.

Please ensure that you follow safety guidelines while using WiSer devices.

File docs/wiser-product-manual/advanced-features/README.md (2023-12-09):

# Advanced Features

### Firmware Updates 

Both WiSer devices feature the ability to update their firmware through a USB connection, facilitated by the dedicated boot button on the device, allowing for a seamless transition into bootloader mode. WiSer devices may receive firmware updates to enhance performance and add new features. Check our website for firmware updates and follow the provided instructions to update your devices.

### Independent ESP32-S2 Dev Boards 

In addition to their primary function as WiSer devices for wireless serial communication, both WiSer-USB and WiSer-TTL possess advanced capabilities. You can use them as independent ESP32-S2 development boards for your personal projects. You can also integrate these small-sized boards into your product’s board easily.

**Note:** Once you overwrite the firmware in WiSer devices, they will no longer function as WiSer devices for wireless serial communication.

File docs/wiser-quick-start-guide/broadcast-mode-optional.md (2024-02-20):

# Broadcast Mode (Optional)

### **Enable Broadcast Mode (Optional)**

If you have multiple WiSer-enabled devices and want to establish wireless serial communication between them without physical cables, you can enable the Broadcast Mode. This mode allows seamless serial communication between multiple devices in your environment.

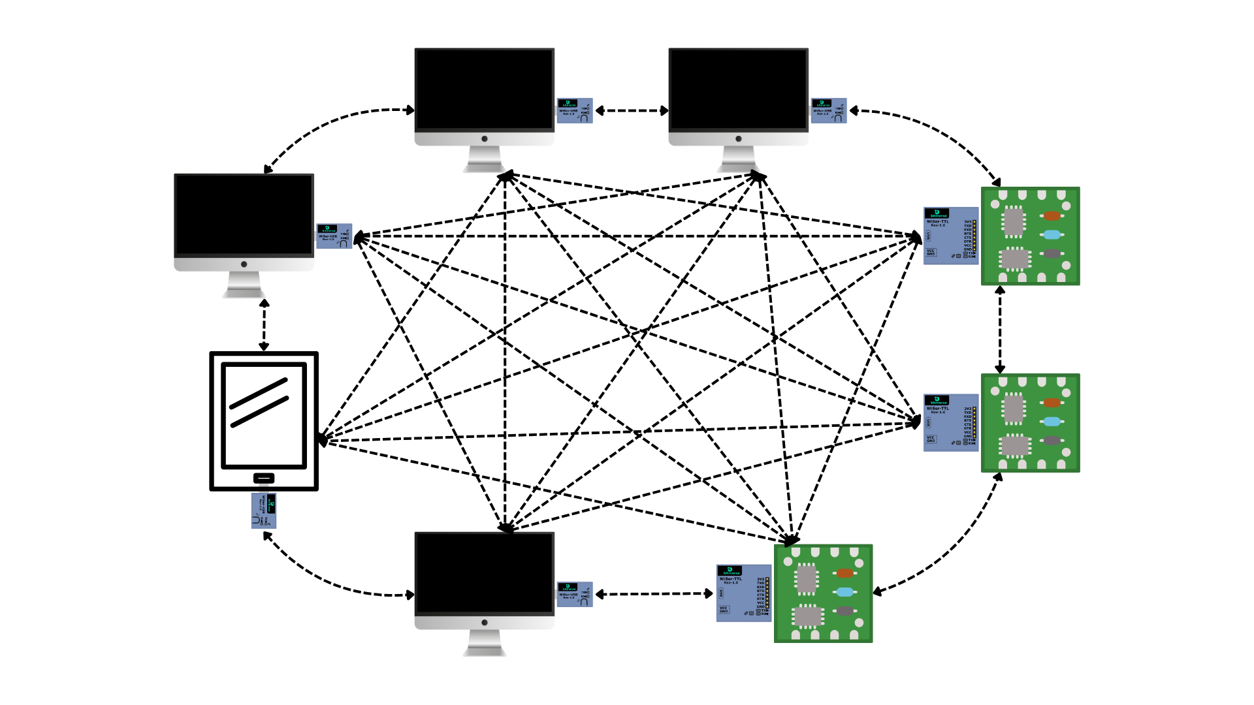
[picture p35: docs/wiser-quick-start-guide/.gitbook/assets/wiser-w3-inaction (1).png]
<figure><figcaption></figcaption></figure>

#### **How to Enable**

* To enable the broadcast mode in WiSer devices, read the firmware's [README.md](../../src/) file.&#x20;

#### **Using Broadcast Mode**

* Once enabled, each host system or embedded device connected to a WiSer-USB or WiSer-TTL device gains the ability to broadcast data to all other connected devices.

**Note:**&#x20;

* Enabling Broadcast mode disables internal encryption in WiSer devices. But, you can always add encryption and device filtration in your application code.
* By default, WiSer devices are equipped with firmware that includes pre-paired devices, facilitating secure point-to-point wireless serial communication with data encryption enabled. Please be aware that the Broadcast mode is disabled by default.

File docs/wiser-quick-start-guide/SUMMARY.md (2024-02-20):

# Table of contents

* [Introduction](README.md)
* [Package Contents](package-contents.md)
* [WiSer Setup](wiser-setup/README.md)
  * [WiSer Devices connection setup](wiser-setup/README.md#\_toc150171902)
  * [Powering On the Devices](wiser-setup/README.md#\_toc150171905)
  * [LED Indicators](wiser-setup/README.md#\_toc150171908)
* [Driver Installation](driver-installation/README.md)
  * [No Drivers Required for WiSer](driver-installation/README.md#\_toc150171912)
* [Using Wiser](using-wiser/README.md)
  * [WiSer Devices Connection Setup](using-wiser/README.md#\_toc150171914)
  * [Accessing the Serial Port](using-wiser/README.md#\_toc150171916)
  * [Baud Rate Configuration](using-wiser/README.md#\_toc150171917)
  * [Flow Control Options](using-wiser/README.md#\_toc150171918)
  * [DTR Control Signal](using-wiser/README.md#\_toc150171919)
  * [Data bit, Parity and Stop bits](using-wiser/README.md#data-bit-parity-and-stop-bits)
  * [Initiating Serial Communication](using-wiser/README.md#\_toc150171920)
* [Broadcast Mode (Optional)](broadcast-mode-optional.md)
* [Troubleshooting](troubleshooting.md)

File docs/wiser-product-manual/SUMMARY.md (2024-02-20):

# Table of contents

* [Introduction](README.md)
  * [Introduction to WiSer](README.md#\_toc150171884)
  * [Key Features](README.md#\_toc150171885)
  * [List of Potential applications using WiSer](README.md#\_toc150171886)
* [Package Contents](package-contents/README.md)
  * [What's Included](package-contents/README.md#\_toc150171888)
* [Getting Started](getting-started/README.md)
  * [Device Overview](getting-started/README.md#\_toc150171894)
  * [System Requirements](getting-started/README.md#\_toc150171897)
  * [Safety Precautions](getting-started/README.md#\_toc150171900)
* [WiSer Setup](wiser-setup/README.md)
  * [WiSer Devices connection setup](wiser-setup/README.md#\_toc150171902)
  * [Powering On the Devices](wiser-setup/README.md#\_toc150171905)
  * [LED Indicators](wiser-setup/README.md#\_toc150171908)
* [Driver Installation](driver-installation/README.md)
  * [No Drivers Required for WiSer](driver-installation/README.md#\_toc150171912)
* [Using Wiser](using-wiser/README.md)
  * [WiSer Devices Connection Setup](using-wiser/README.md#\_toc150171914)
  * [Accessing the Serial Port](using-wiser/README.md#\_toc150171916)
  * [Baud Rate Configuration](using-wiser/README.md#\_toc150171917)
  * [Flow Control Options](using-wiser/README.md#\_toc150171918)
  * [DTR Control Signal](using-wiser/README.md#\_toc150171919)
  * [Data bit, Parity and Stop bits](using-wiser/README.md#data-bit-parity-and-stop-bits)
  * [Initiating Serial Communication](using-wiser/README.md#\_toc150171920)
* [Broadcast Mode (Optional)](broadcast-mode-optional.md)
* [Wireless Connectivity](wireless-connectivity/README.md)
  * [Pairing WiSer Devices](wireless-connectivity/README.md#\_toc150171924)
  * [Connecting to Embedded Devices](wireless-connectivity/README.md#\_toc150171925)
  * [Troubleshooting Wireless Connections](wireless-connectivity/README.md#\_toc150171926)
* [Advanced Features](advanced-features/README.md)
  * [Firmware Updates](advanced-features/README.md#\_toc150171929)
  * [Independent ESP32-S2 Dev Boards](advanced-features/README.md#\_toc150171930)
* [Frequently Asked Questions (FAQ)](frequently-asked-questions-faq/README.md)
  * [Common Issues and Solutions](frequently-asked-questions-faq/README.md#\_toc150171932)
* [Technical Specifications](technical-specifications/README.md)
  * [Device Specifications](technical-specifications/README.md#\_toc150171934)
  * [Compliance Information](technical-specifications/README.md#\_toc150171935)
* [Further Support](further-support/README.md)
  * [Customer Support Contact](further-support/README.md#\_toc150171938)
* [Appendix](appendix/README.md)
  * [Glossary of Terms](appendix/README.md#\_toc150171940)
  * [Regulatory Information](appendix/README.md#\_toc150171941)

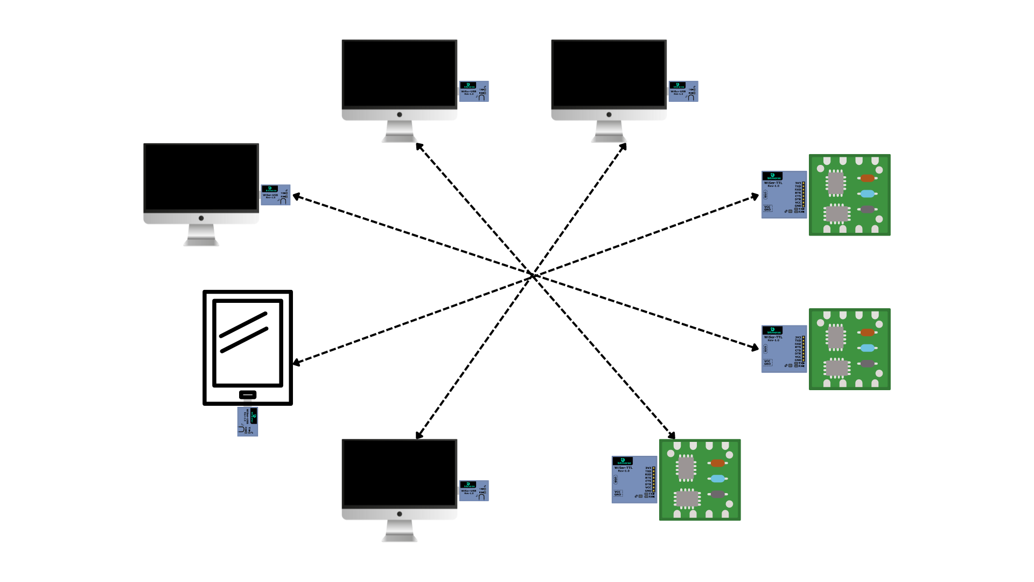
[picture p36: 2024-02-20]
docs/wiser-quick-start-guide/.gitbook/assets/wiser-w3-inaction.png

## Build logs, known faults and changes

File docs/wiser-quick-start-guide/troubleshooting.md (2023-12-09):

# Troubleshooting

If you encounter any issues, please consult the Troubleshooting section in the product manual.

For detailed information and advanced features, regulatory information, and add-ons, refer to the complete product manual.

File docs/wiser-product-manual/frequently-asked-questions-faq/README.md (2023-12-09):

# Frequently Asked Questions (FAQ)

### Common Issues and Solutions 

Please consult the Frequently Asked Questions section on our website for solutions to common issues and additional guidance. If your question is not addressed there, don't hesitate to [reach out to our customer support team](mailto:support@bitmerse.com) for assistance.

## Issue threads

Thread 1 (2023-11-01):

Question about hardware flow control

gitcnd, 2023-11-01:
Hi - are you 100% sure your hardware flow control works?

I've got a Roland Modela MDX20 milling machine, and "old" computers with physical serial ports work great, but almost all the windows USB cables (even ones that claim hardware flow control) do not actually do the flow control properly...

Your project would be amazing for my needs - milling machines make a HUGE mess and lots of noise - not anything you want next to your expensive CAD workstations :-)

jaydeepd, 2023-11-02:
Hi @gitcnd, The hardware flow control feature underwent thorough testing with STM32 MCUs, ESP32 MCUs, Raspberry Pi and other MCUs, with RTS/CTS hardware flow control enabled. In these tests, the WiSer device performed well without any issues. So, I am confident that it will also work effectively with your milling machine. Please note that you may require a TTL-to-RS232 converter to use it in conjunction with your milling machine.

BTW, have you tried using [these USB to serial cables](https://365rolanddgnam.sharepoint.com/:b:/s/Dealers/EcfRs9hw-IBPmH7z_BcsYEsBz27kXGV5i8zlwQ3KiJ86iw)? The machine manufacturer claims that they are supported with machine.

gitcnd, 2023-11-02:
Hi Jaydeep,

Thanks for the personal reply!

I do have that exact cable in the photo, but I'm still using a hardware serial port on a spare PC after "giving up" on a pile of other cables beforehand (the new one arrived after I gave up).

It's a tricky problem to diagnose on the Roland - since random parts of the RML stream (which looks like gcode) simply get "dropped" if the sending machine doesn't stop sending when told (when the RML buffer is full), so the problem can only be detected when the RML code arrives faster than the tool can move, and then "random crazy stuff" happens next (usually out-of-bound grinding and breaking the milling bit).

I guess the whole concept is a moot point really - if it happens not to work when I get it, since it's open-source, it can be fixed then anyhow (I'm an MCU driver-author myself already :-)

Kind Regards,
Chris Drake

Closed 2023-11-02.

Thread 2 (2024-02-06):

5v TTL Support?

biggestsonicfan, 2024-02-06:
Greetings! Love the concept and idea, but I see only "3.3v" marked on the WiSer-TTL unit. Does this mean 5v TTL isn't supported or would that require component modification on the board?

biggestsonicfan, 2024-02-28:
[Congrats](https://www.crowdsupply.com/bitmerse/wiser/updates/wiser-now-supports-both-3-3v-and-5v-ttl-levels)!🥳

bitmerse, 2024-02-28:
Thanks @biggestsonicfan!

>Oh but can you power the device with the serial system's 5v?

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

Yes, you can power up the target device using WiSer-TTL's VCC pin on the serial side (marked in green).
In case you want to power-up WiSer-TTL using target device's 5V, you can connect the 5V to VCC pin on USB side (marked in red).

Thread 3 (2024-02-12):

Antenna layout deviates from very specific MFG instruction.

tomfleet, 2024-02-12:
The layout for the 2.4GHz antenna (Johanson P/N 2450AT18B100) deviates from what is given in the datasheet, and additional mfg application guidance, and will very likely have a significant impact on range.

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

The gap shown here is specified as 4mm **minimum** in the datasheet, and in other places, such as

https://www.johansontechnology.com/chip-antenna-layout-for-802-11-applications

I think that it would possible to shift a few bits about to achieve this... Otherwise, if you are fixed on the design, I think that it would be kind to give test reports on the resultant RF performance?

tomfleet, 2024-02-12:
In fact, the TTL version of this pair of boards has no reason **not** to have adhered to the  layout guidelines...

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

At least that one is a very easy fix, if desired! :)

jaydeepd, 2024-02-13:
@tomfleet, First of all, I appreciate your feedback. Thanks for pointing out the antenna layout deviation from specs. I'll review it closely and explore adjustments to meet the specified 4mm minimum gap on both the TTL and USB versions. We will incorporate these changes into the production version.

Your input is crucial; feel free to share more insights. We're committed to delivering a quality product, and every piece of feedback matters.

Closed 2024-02-13.

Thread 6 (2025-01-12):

WiSer-TTL LED documentation?

biggestsonicfan, 2025-01-12:
Greetings again,

I just received my Crowd Supply order yesterday and I couldn't find any documentation about the TTL module slowly blinking. Apparently this is a sort of "waiting to pair" indicator? I had previously powered it up several times and the connection was almost instant, so suddenly seeing it start blinking until it stopped made me wonder if it was an error code.

jaydeepd, 2025-01-13:
Hi @biggestsonicfan,

Thank you for reaching out. The CONN LED on WiSer devices is triggered when the button on the WiSer-USB is pressed.
The slowly blinking LED indicates the deactivation of hardware flow control (RTS and DTR pins). I assume the button was pressed accidentally for more than 2 seconds. Pressing it again for more than 2 seconds reactivates the hardware flow control. Pressing it for less than 2 seconds causes a solid LED to appear on both devices (WiSer-USB and WiSer-TTL), indicating a "paired" relationship between them.

Please note that both devices are pre-paired at the factory, and you cannot unpair them without performing a firmware wipeout on both devices.

The LED related documentation is available here: https://bitmerse.gitbook.io/wiser-product-manual/wiser-setup#toc150171910

Let me know if you have any further questions.

biggestsonicfan, 2025-01-13:
Unsure how I missed that one, thanks!

Closed 2025-01-13.

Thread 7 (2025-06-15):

WiSer can't connect when VCC is applied to TTL side.

biggestsonicfan, 2025-06-15:
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

 _Originally posted by @ghost in [#2](https://github.com/bitmerse/WiSer/issues/2#issuecomment-1968559078)_

I am able to power the unit by sending 5v to VCC marked in green, but the unit is unable to respond to the dongle button press to indicate a successful connection between the two units.

jaydeepd, 2025-06-15:
Hi @biggestsonicfan

Thanks for reaching out again. Let me rephrase the differences between the two VCC pins:

- The **VCC pin marked in red** is an **input voltage pin** for the WiSer-TTL unit. This provides an alternate power supply option in case you don’t want to use the USB Type-C port to power the WiSer-TTL.

- The **VCC pin marked in green** is an **output voltage pin** from the WiSer-TTL unit. You can use this pin to supply 5V to your target board or embedded device.

> I am able to power the unit by sending 5v to VCC marked in green, but the unit is unable to respond to the dongle button press to indicate a successful connection between the two units.

Unless I'm misunderstanding something, you're trying to power the WiSer-TTL using the VCC pin marked in green, right?
That won't work, because this pin is a 5V output from the WiSer-TTL. If you want to supply 5V power to the WiSer-TTL using a jumper cable, you should use the **VCC pin marked in red**.

Hope this clears up any confusion. Feel free to reach out in case of any further queries.

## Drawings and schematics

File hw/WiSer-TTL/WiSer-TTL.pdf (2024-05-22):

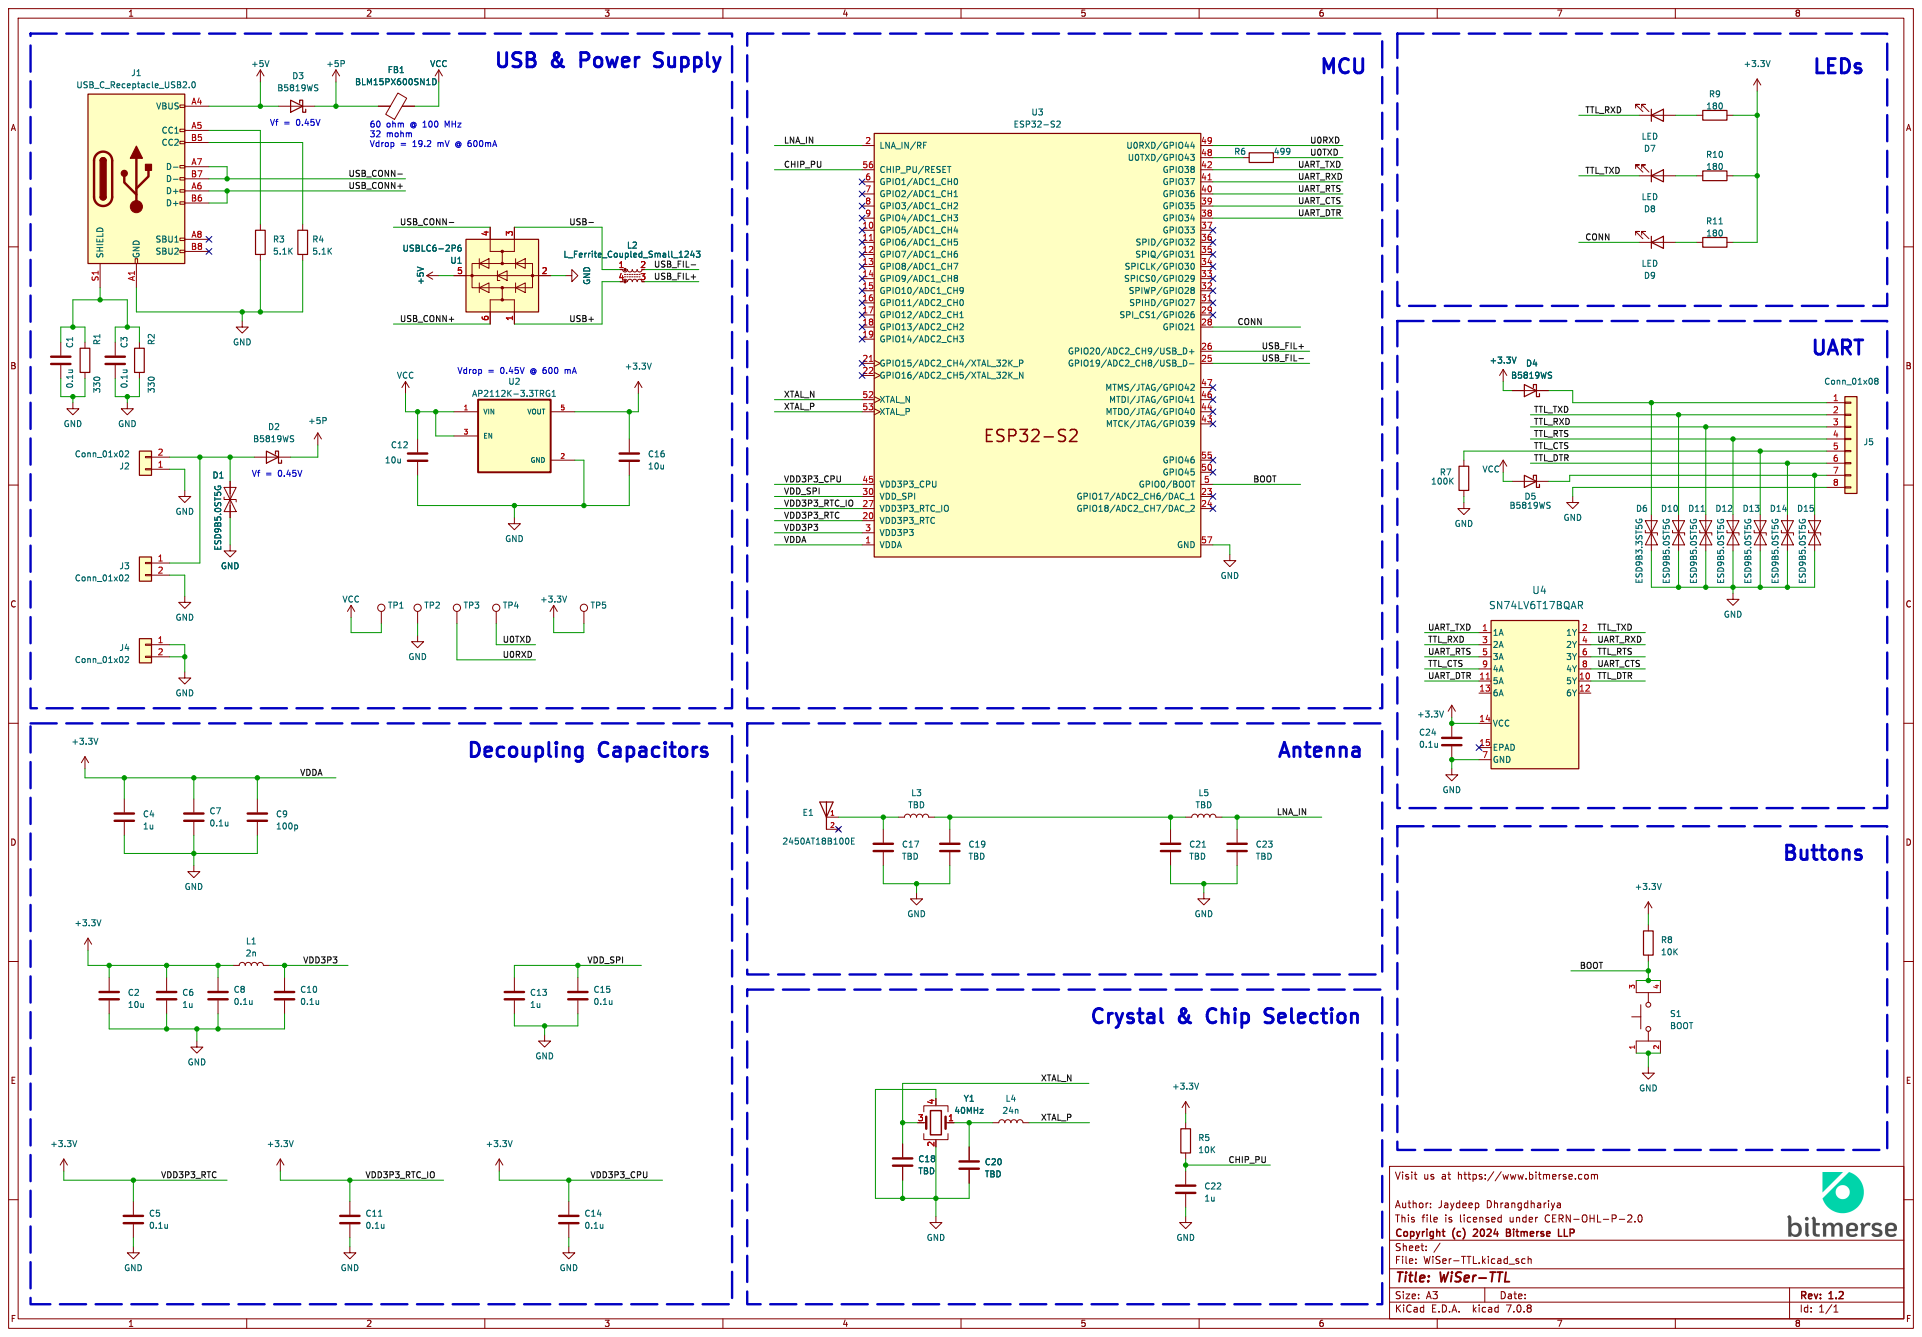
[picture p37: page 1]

Id: 1/1 Title: WiSer-TTL

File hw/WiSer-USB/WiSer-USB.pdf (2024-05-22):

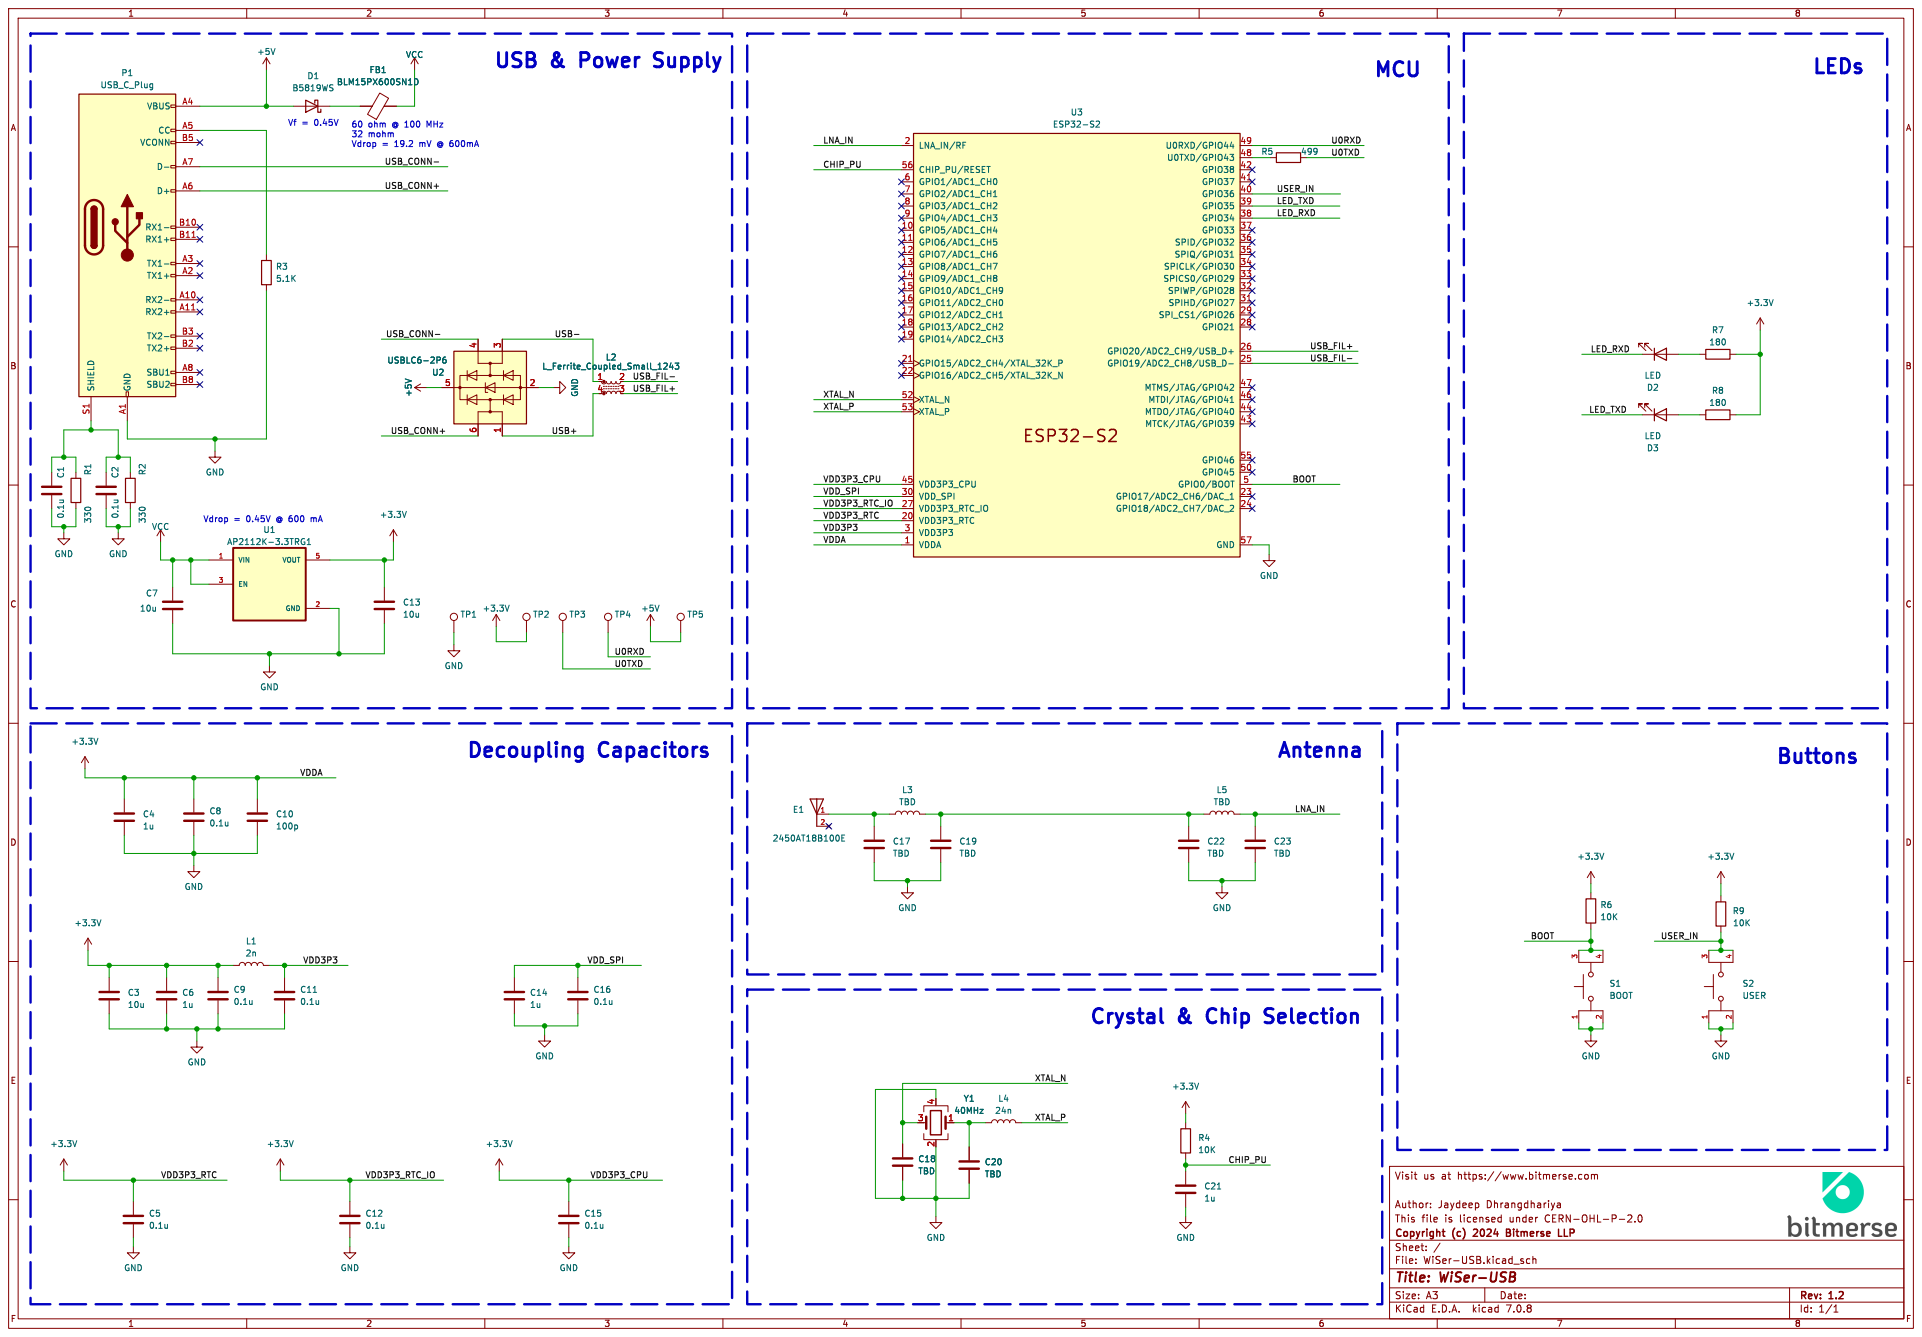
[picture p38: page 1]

Id: 1/1 Title: WiSer-USB

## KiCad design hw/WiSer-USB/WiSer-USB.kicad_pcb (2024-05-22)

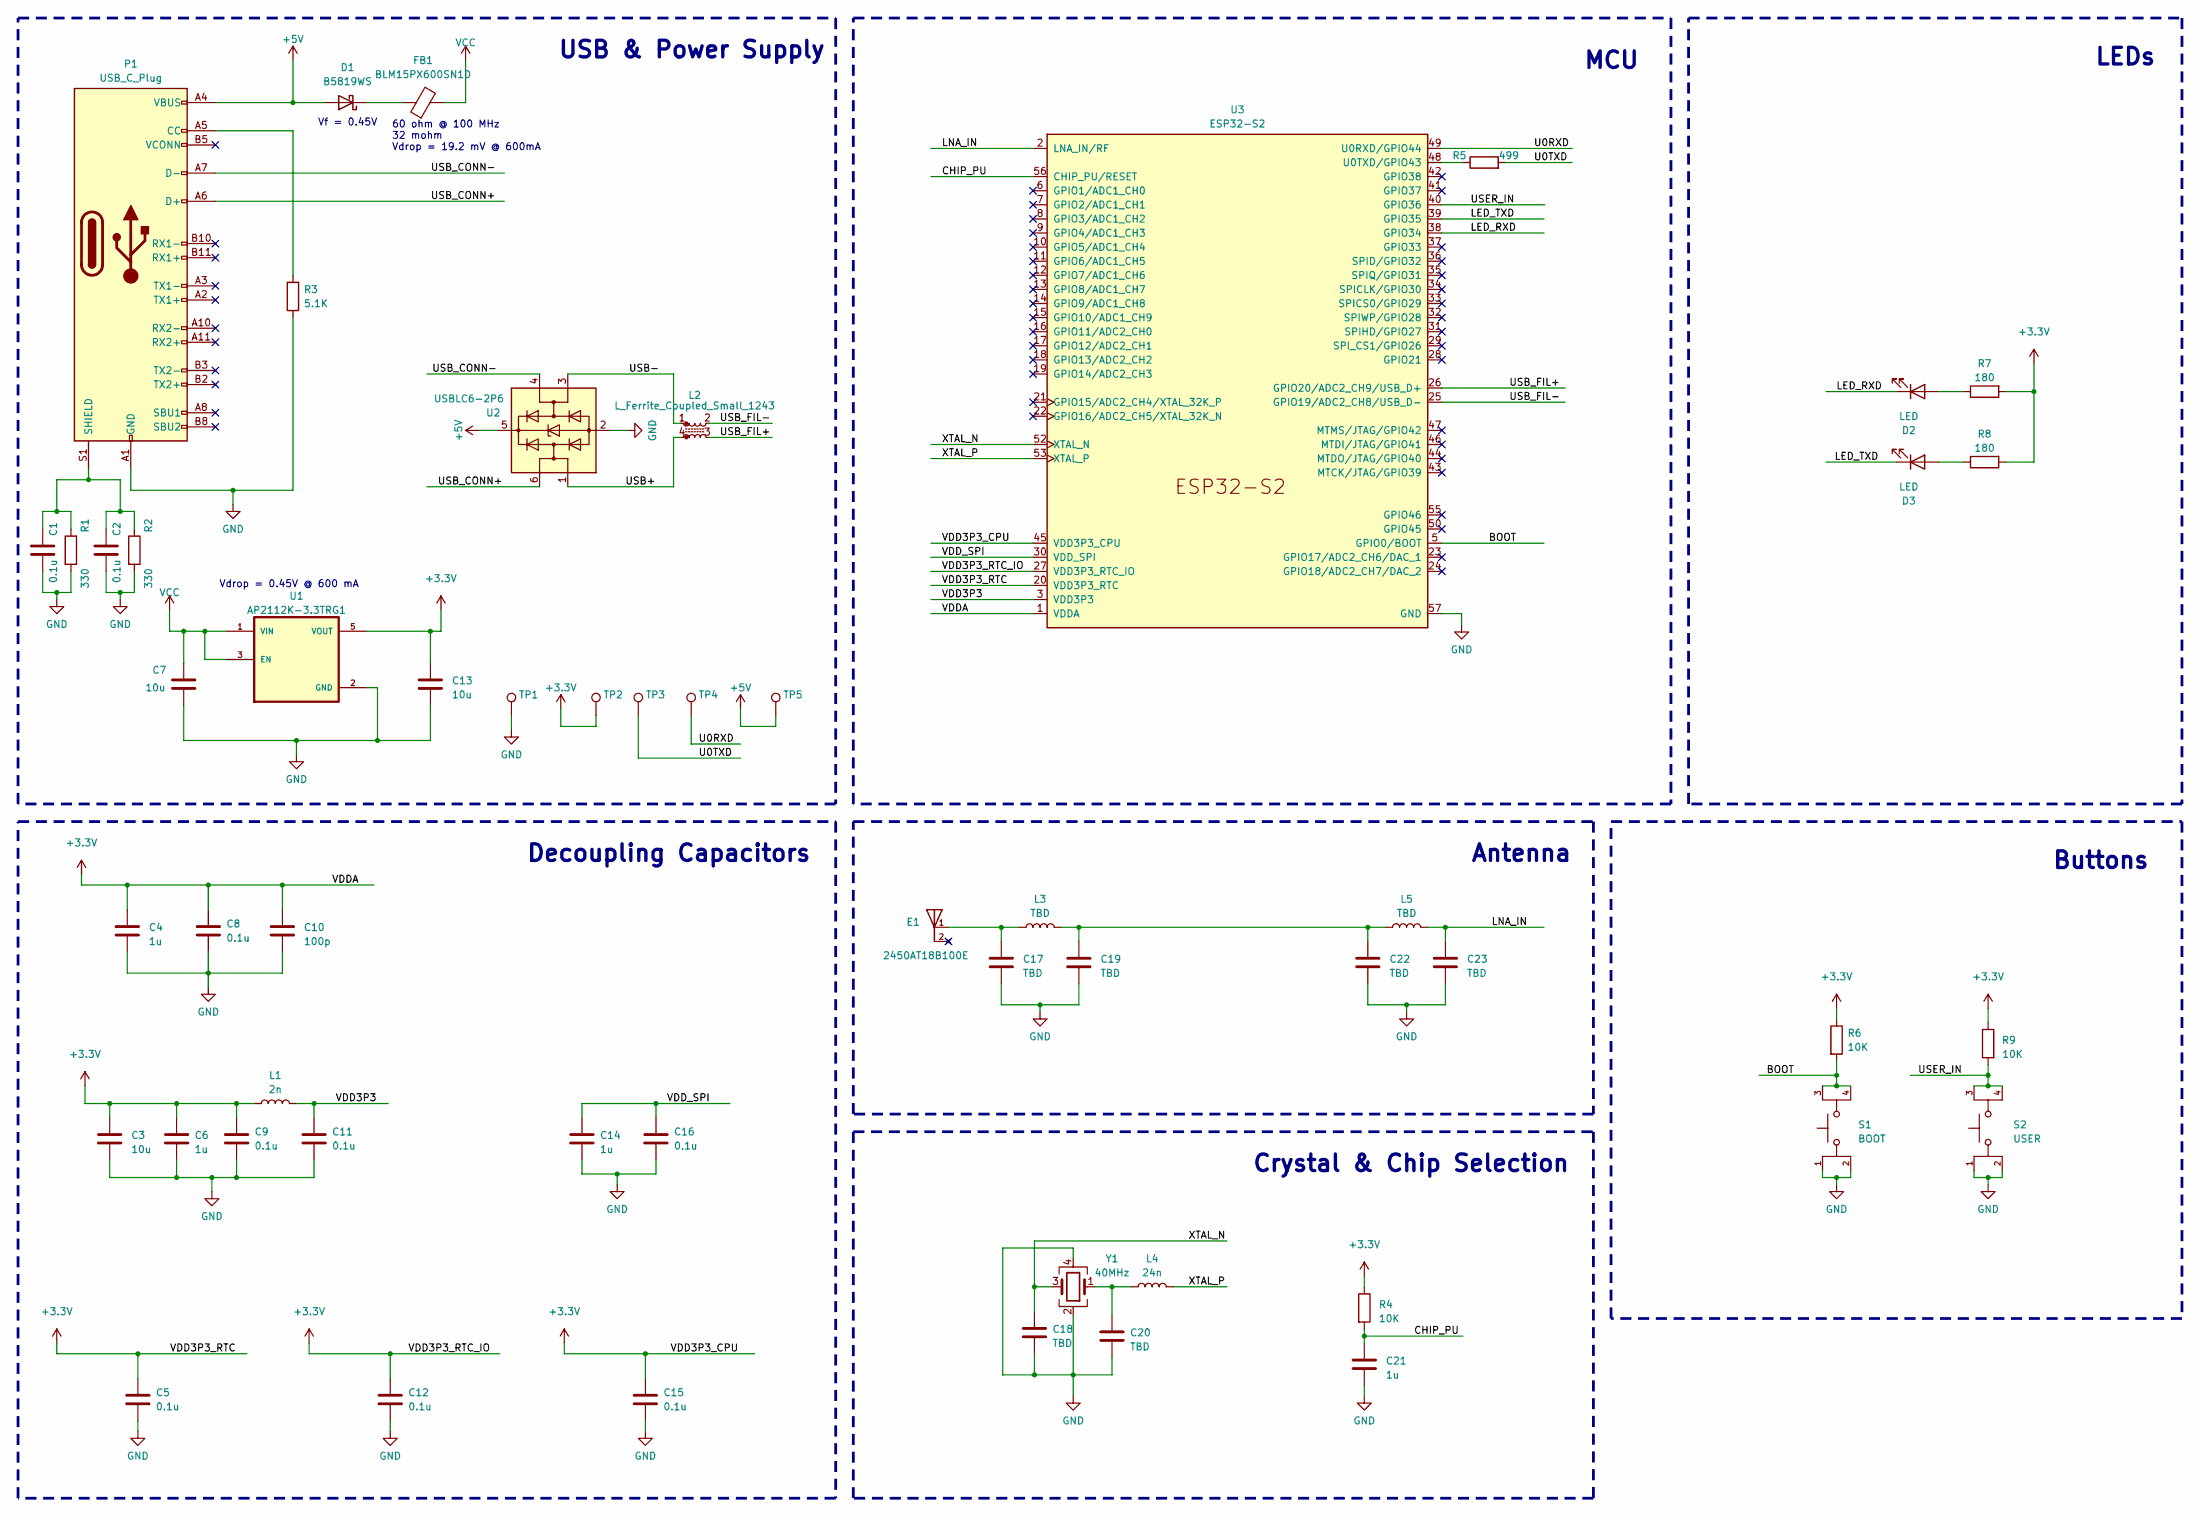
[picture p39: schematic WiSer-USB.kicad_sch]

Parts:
C1, C2, C5, C8, C9, C11, C12, C15, C16: 0.1u; C_0402_1005Metric
C3, C7, C13: 10u; C_0402_1005Metric
C4, C6, C14, C21: 1u; C_0402_1005Metric
C10: 100p; C_0402_1005Metric
C17, C18, C19, C20, C22, C23: TBD; C_0402_1005Metric
D1: B5819WS; D_SOD-323_HandSoldering
D2, D3: LED; LED_0402_1005Metric_Pad0.77x0.64mm_HandSolder
E1: 2450AT18B100E; XDCR_2450AT18B100E; PARTREV 4.0
FB1: BLM15PX600SN1D; R_0402_1005Metric
L1: 2n; L_0402_1005Metric
L2: L_Ferrite_Coupled_Small_1243; FIL_DLM0NSM900HY2D
L3, L5: TBD; L_0402_1005Metric
L4: 24n; L_0402_1005Metric
P1: USB_C_Plug; USB-C-Male-Conn
R1, R2: 330; R_0402_1005Metric
R3: 5.1K; R_0402_1005Metric
R4, R6, R9: 10K; R_0402_1005Metric
R5: 499; R_0402_1005Metric
R7, R8: 180; R_0402_1005Metric
S1: BOOT; SW_TL3365AF180QG; PARTREV A
S2: USER; SW_TL3365AF180QG; PARTREV A
TP1: GND; TestPoint_Pad_D0.8mm
TP2: 3V3; TestPoint_Pad_D0.8mm
TP3: U0RXD; TestPoint_Pad_D0.8mm
TP4: U0TXD; TestPoint_Pad_D0.8mm
TP5: 5V; TestPoint_Pad_D0.8mm
U1: AP2112K-3.3TRG1; SOT95P285X140-5N; PARTREV 2-2
U2: USBLC6-2P6; SOT50P160X60-6N
U3: ESP32-S2
Y1: 40MHz; Crystal_SMD_2016-4Pin_2.0x1.6mm

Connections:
+3V3: C3.1, C4.1, C5.1, C6.1, C8.1, C9.1, C10.1, C12.1, C13.1, C15.1, L1.1, R4.1, R6.1, R7.2, R8.2, R9.1, TP2.1, U1.5 (VOUT), U3.1 (VDDA), U3.20 (VDD3P3_RTC), U3.27 (VDD3P3_RTC_IO), U3.45 (VDD3P3_CPU), U3.51 (VDDA), U3.54 (VDDA)
+5V: D1.2 (A), P1.A4 (VBUS), P1.A9 (VBUS), P1.B4 (VBUS), P1.B9 (VBUS), TP5.1, U2.5 (VBUS)
/BOOT: R6.2, S1.3, S1.4, U3.5 (GPIO0/BOOT)
/CHIP_PU: C21.1, R4.2, U3.56 (CHIP_PU/RESET)
/LED_RXD: D2.1 (K), U3.38 (GPIO34)
/LED_TXD: D3.1 (K), U3.39 (GPIO35)
/LNA_IN: C23.1, L5.1, U3.2 (LNA_IN/RF)
/U0RXD: TP4.1, U3.49 (U0RXD/GPIO44)
/U0TXD: R5.2, TP3.1
/USB+: L2.4, U2.1 (I/O1)
/USB-: L2.1, U2.3 (I/O2)
/USB_CONN+: P1.A6 (D+), U2.6 (I/O1)
/USB_CONN-: P1.A7 (D-), U2.4 (I/O2)
/USB_FIL+: L2.3, U3.26 (GPIO20/ADC2_CH9/USB_D+)
/USB_FIL-: L2.2, U3.25 (GPIO19/ADC2_CH8/USB_D-)
/USER_IN: R9.2, S2.3, S2.4, U3.40 (GPIO36)
/VDD3P3: C11.1, L1.2, U3.3 (VDD3P3), U3.4 (VDD3P3)
/VDD_SPI: C14.1, C16.1, U3.30 (VDD_SPI)
/XTAL_N: C18.1, U3.52 (XTAL_N), Y1.3
/XTAL_P: L4.2, U3.53 (XTAL_P)
GND: C1.2, C2.2, C3.2, C4.2, C5.2, C6.2, C7.2, C8.2, C9.2, C10.2, C11.2, C12.2, C13.2, C14.2, C15.2, C16.2, C17.2, C18.2, C19.2, C20.2, C21.2, C22.2, C23.2, P1.A1 (GND), P1.A12 (GND), P1.B1 (GND), P1.B12 (GND), R1.2, R2.2, R3.1, S1.1, S1.2, S2.1, S2.2, TP1.1, U1.2 (GND), U2.2 (GND), U3.57 (GND), Y1.2, Y1.4
unnamed: C17.1, E1.1, L3.2
unnamed: C19.1, C22.1, L3.1, L5.2
unnamed: C20.1, L4.1, Y1.1
unnamed: D1.1 (K), FB1.1
unnamed: D2.2 (A), R7.1
unnamed: D3.2 (A), R8.1
unnamed: P1.A5 (CC), R3.2
unnamed: C1.1, C2.1, P1.S1 (SHIELD), R1.1, R2.1
unnamed: R5.1, U3.48 (U0TXD/GPIO43)
VCC: C7.1, FB1.2, U1.1 (VIN), U1.3 (EN)

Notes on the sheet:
Crystal & Chip Selection
Vf = 0.45V
LEDs
Decoupling Capacitors
Buttons
USB & Power Supply
60 ohm @ 100 MHz 32 mohm Vdrop = 19.2 mV @ 600mA
Antenna
MCU
Vdrop = 0.45V @ 600 mA

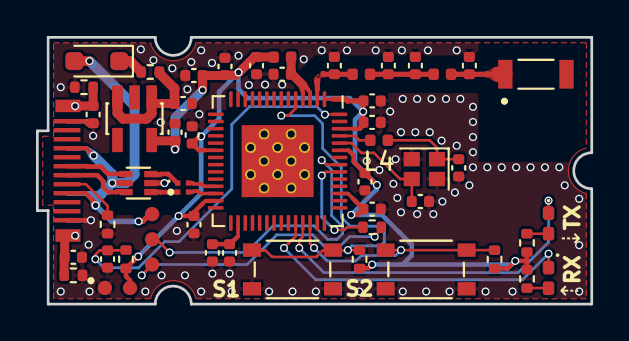
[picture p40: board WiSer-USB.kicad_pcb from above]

Board: 4 copper layers, 30.8 x 14.8 mm, 54 parts (0 on the bottom side), 31 nets.

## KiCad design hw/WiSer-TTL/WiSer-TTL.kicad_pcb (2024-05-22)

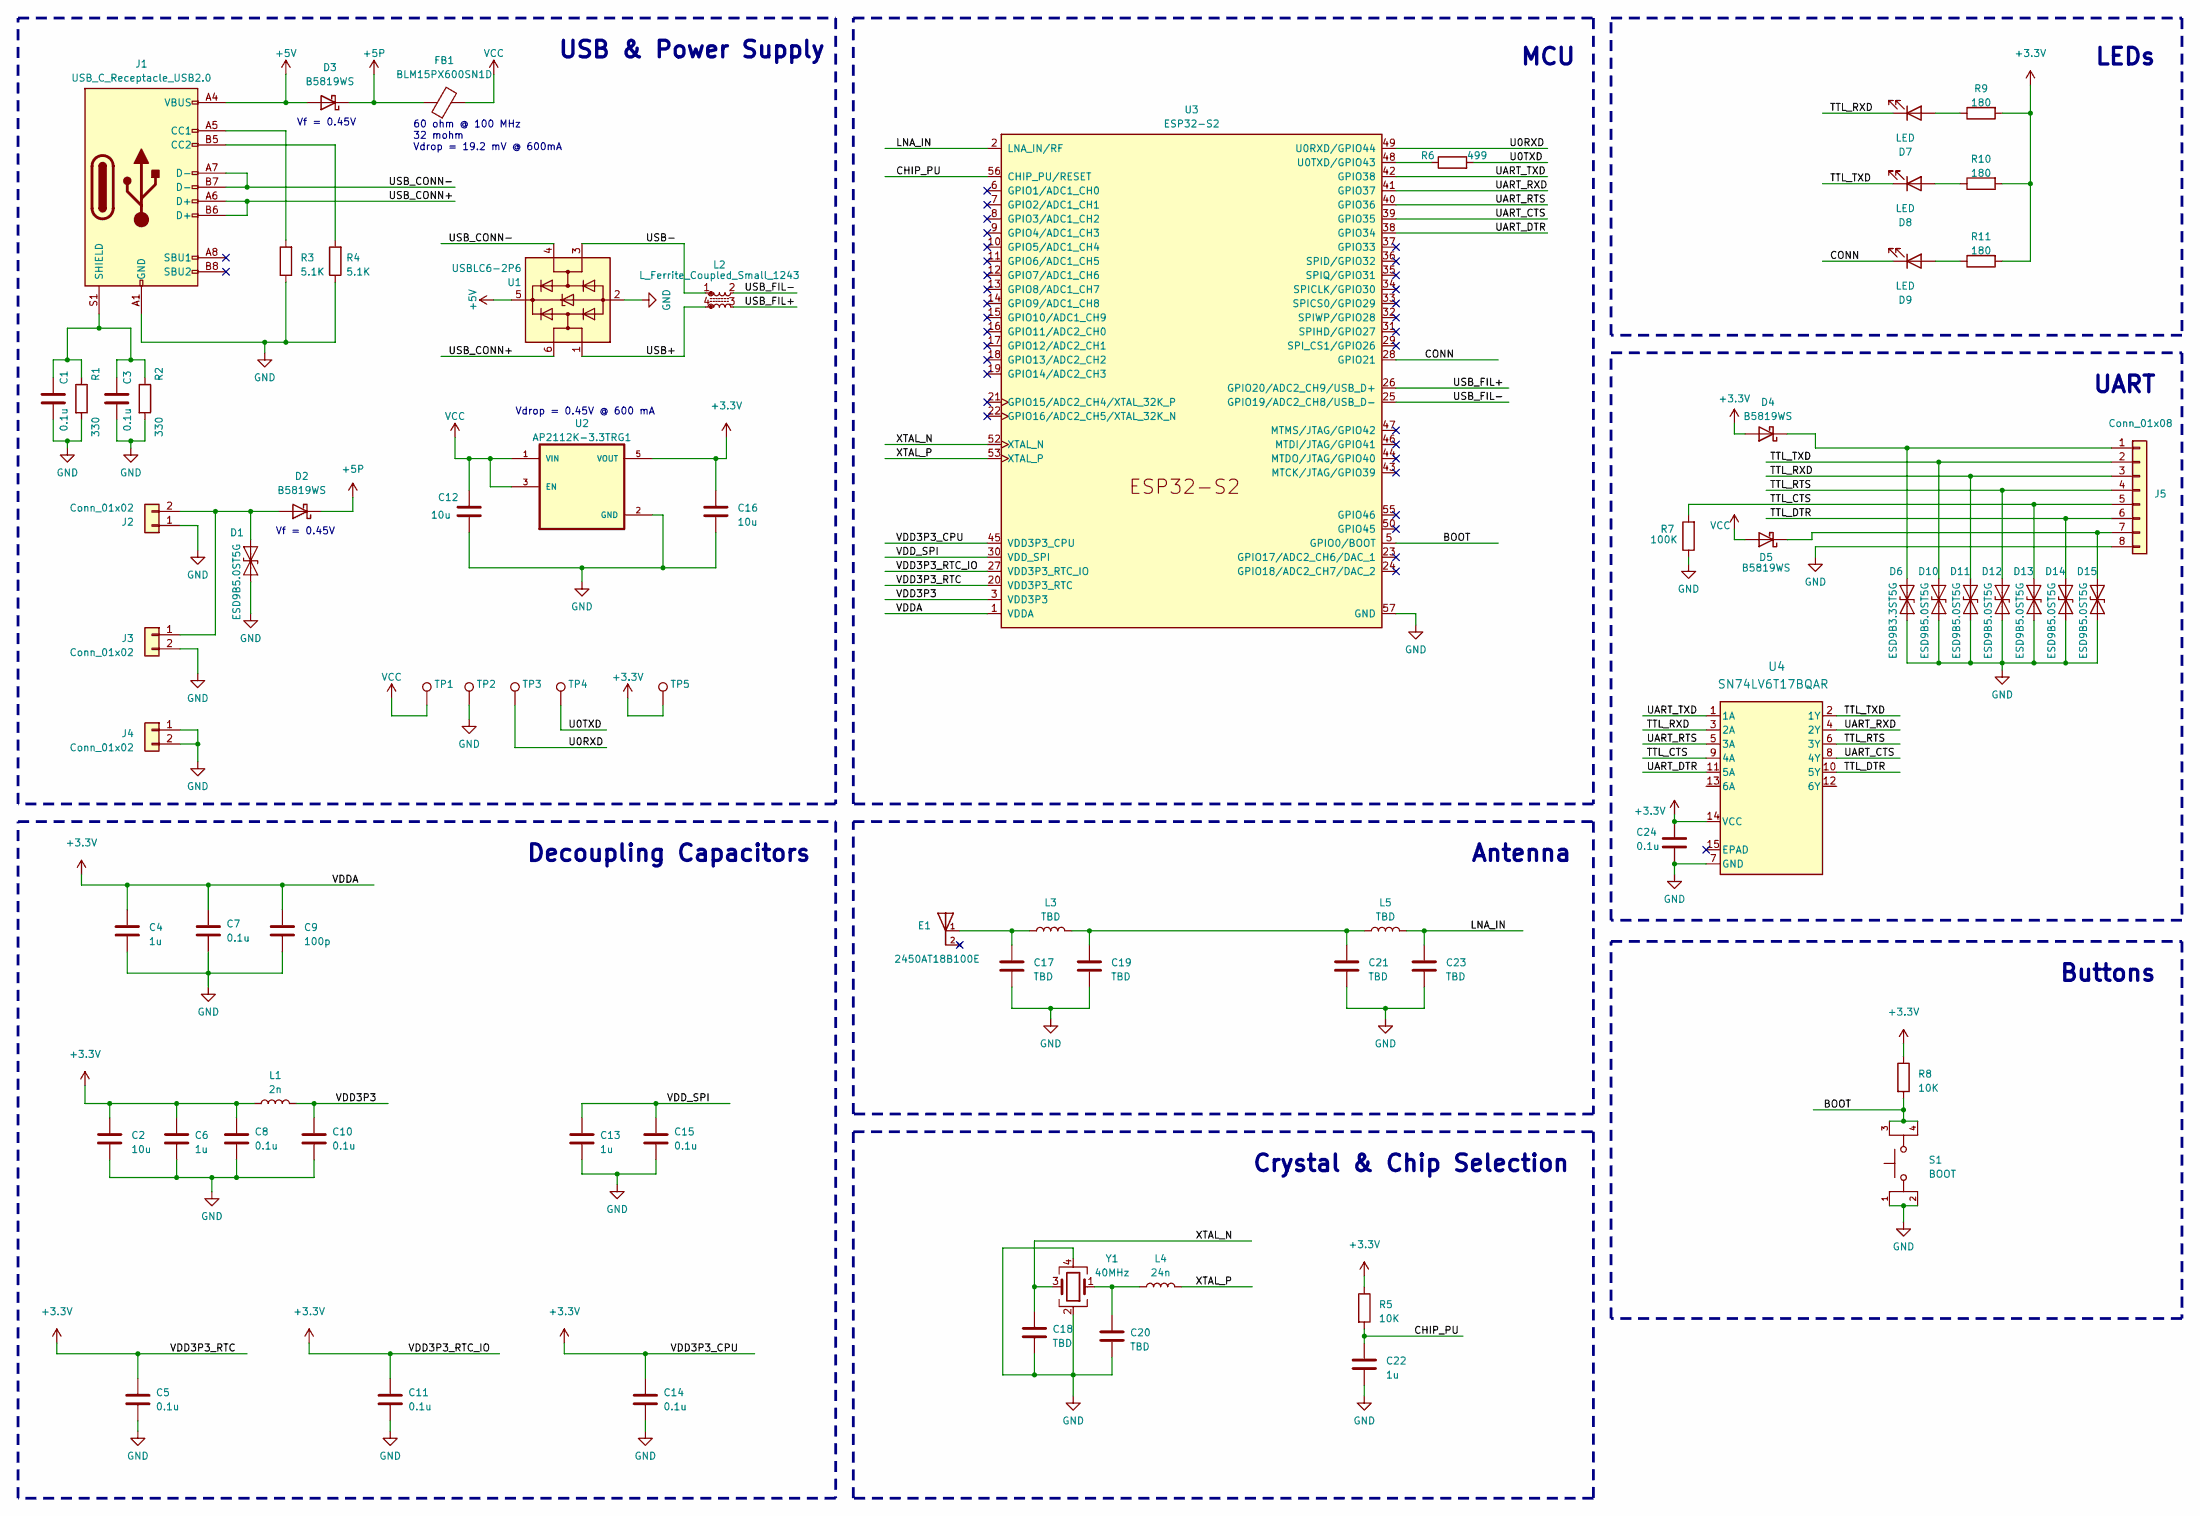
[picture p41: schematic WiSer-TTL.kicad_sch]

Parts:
C1, C3, C5, C7, C8, C10, C11, C14, C15, C24: 0.1u; C_0402_1005Metric
C2, C12, C16: 10u; C_0402_1005Metric
C4, C6, C13, C22: 1u; C_0402_1005Metric
C9: 100p; C_0402_1005Metric
C17, C18, C19, C20, C21, C23: TBD; C_0402_1005Metric
D1, D10, D11, D12, D13, D14, D15: ESD9B5.0ST5G; D_SOD-923
D2, D3, D4, D5: B5819WS; D_SOD-323_HandSoldering
D6: ESD9B3.3ST5G; D_SOD-923
D7, D8, D9: LED; LED_0402_1005Metric_Pad0.77x0.64mm_HandSolder
E1: 2450AT18B100E; XDCR_2450AT18B100E; PARTREV 4.0
FB1: BLM15PX600SN1D; R_0402_1005Metric
J1: USB_C_Receptacle_USB2.0; USB_C_Receptacle_G-Switch_GT-USB-7010ASV
J2: Conn_01x02; PinHeader_1x02_P2.54mm_Horizontal
J3, J4: Conn_01x02; PinHeader_1x02_P2.54mm_Vertical
J5: Conn_01x08; PinHeader_1x08_P2.54mm_Horizontal
L1: 2n; L_0402_1005Metric
L2: L_Ferrite_Coupled_Small_1243; FIL_DLM0NSM900HY2D
L3, L5: TBD; L_0402_1005Metric
L4: 24n; L_0402_1005Metric
R1, R2: 330; R_0402_1005Metric
R3, R4: 5.1K; R_0402_1005Metric
R5, R8: 10K; R_0402_1005Metric
R6: 499; R_0402_1005Metric
R7: 100K; R_0402_1005Metric
R9, R10, R11: 180; R_0402_1005Metric
S1: BOOT; SW_TL3365AF180QG; PARTREV A
TP1: 5V; TestPoint_Pad_D0.8mm
TP2, TP4: GND; TestPoint_Pad_D0.8mm
TP3: U0RXD; TestPoint_Pad_D0.8mm
TP5: 3V3; TestPoint_Pad_D0.8mm
U1: USBLC6-2P6; SOT50P160X60-6N
U2: AP2112K-3.3TRG1; SOT95P285X140-5N; PARTREV 2-2
U3: ESP32-S2
U4: SN74LV6T17BQAR; WQFN14_BQA_TEX
Y1: 40MHz; Crystal_SMD_2016-4Pin_2.0x1.6mm

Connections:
+3V3: C2.1, C4.1, C5.1, C6.1, C7.1, C8.1, C9.1, C11.1, C14.1, C16.1, C24.1, D4.2 (A), L1.1, R5.1, R8.1, R9.2, R10.2, R11.2, TP5.1, U2.5 (VOUT), U3.1 (VDDA), U3.20 (VDD3P3_RTC), U3.27 (VDD3P3_RTC_IO), U3.45 (VDD3P3_CPU), U3.51 (VDDA), U3.54 (VDDA), U4.14 (VCC)
+5P: D2.1 (K), D3.1 (K), FB1.1
+5V: D3.2 (A), J1.A4 (VBUS), J1.A9 (VBUS), J1.B4 (VBUS), J1.B9 (VBUS), U1.5 (VBUS)
/BOOT: R8.2, S1.3, S1.4, U3.5 (GPIO0/BOOT)
/CHIP_PU: C22.1, R5.2, U3.56 (CHIP_PU/RESET)
/CONN: D9.1 (K), U3.28 (GPIO21)
/LNA_IN: C23.1, L5.2, U3.2 (LNA_IN/RF)
/TTL_CTS: D13.2 (A2), J5.5, R7.2, U4.9 (4A)
/TTL_DTR: D14.2 (A2), J5.6, U4.10 (5Y)
/TTL_RTS: D12.2 (A2), J5.4, U4.6 (3Y)
/TTL_RXD: D7.1 (K), D11.2 (A2), J5.3, U4.3 (2A)
/TTL_TXD: D8.1 (K), D10.2 (A2), J5.2, U4.2 (1Y)
/U0RXD: TP3.1, U3.49 (U0RXD/GPIO44)
/U0TXD: R6.2, TP4.1
/UART_CTS: U3.39 (GPIO35), U4.8 (4Y)
/UART_DTR: U3.38 (GPIO34), U4.11 (5A)
/UART_RTS: U3.40 (GPIO36), U4.5 (3A)
/UART_RXD: U3.41 (GPIO37), U4.4 (2Y)
/UART_TXD: U3.42 (GPIO38), U4.1 (1A)
/USB+: L2.4, U1.1 (I/O1)
/USB-: L2.1, U1.3 (I/O2)
/USB_CONN+: J1.A6 (D+), J1.B6 (D+), U1.6 (I/O1)
/USB_CONN-: J1.A7 (D-), J1.B7 (D-), U1.4 (I/O2)
/USB_FIL+: L2.3, U3.26 (GPIO20/ADC2_CH9/USB_D+)
/USB_FIL-: L2.2, U3.25 (GPIO19/ADC2_CH8/USB_D-)
/VDD3P3: C10.1, L1.2, U3.3 (VDD3P3), U3.4 (VDD3P3)
/VDD_SPI: C13.1, C15.1, U3.30 (VDD_SPI)
/XTAL_N: C18.1, U3.52 (XTAL_N), Y1.3
/XTAL_P: L4.2, U3.53 (XTAL_P)
GND: C1.2, C2.2, C3.2, C4.2, C5.2, C6.2, C7.2, C8.2, C9.2, C10.2, C11.2, C12.2, C13.2, C14.2, C15.2, C16.2, C17.2, C18.2, C19.2, C20.2, C21.2, C22.2, C23.2, C24.2, D1.1 (A1), D6.1 (A1), D10.1 (A1), D11.1 (A1), D12.1 (A1), D13.1 (A1), D14.1 (A1), D15.1 (A1), J1.A1 (GND), J1.A12 (GND), J1.B1 (GND), J1.B12 (GND), J2.1, J3.2, J4.1, J4.2, J5.8, R1.2, R2.2, R3.1, R4.1, R7.1, S1.1, S1.2, TP2.1, U1.2 (GND), U2.2 (GND), U3.57 (GND), U4.7 (GND), Y1.2, Y1.4
unnamed: C17.1, E1.1, L3.1
unnamed: C19.1, C21.1, L3.2, L5.1
unnamed: C20.1, L4.1, Y1.1
unnamed: D1.2 (A2), D2.2 (A), J2.2, J3.1
unnamed: D4.1 (K), D6.2 (A2), J5.1
unnamed: D7.2 (A), R9.1
unnamed: D8.2 (A), R10.1
unnamed: D9.2 (A), R11.1
unnamed: D5.1 (K), D15.2 (A2), J5.7
unnamed: J1.A5 (CC1), R3.2
unnamed: J1.B5 (CC2), R4.2
unnamed: C1.1, C3.1, J1.S1 (SHIELD), R1.1, R2.1
unnamed: R6.1, U3.48 (U0TXD/GPIO43)
VCC: C12.1, D5.2 (A), FB1.2, TP1.1, U2.1 (VIN), U2.3 (EN)

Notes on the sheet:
Crystal & Chip Selection
LEDs
Decoupling Capacitors
Vf = 0.45V
Buttons
USB & Power Supply
UART
Antenna
MCU
60 ohm @ 100 MHz 32 mohm Vdrop = 19.2 mV @ 600mA
Vdrop = 0.45V @ 600 mA

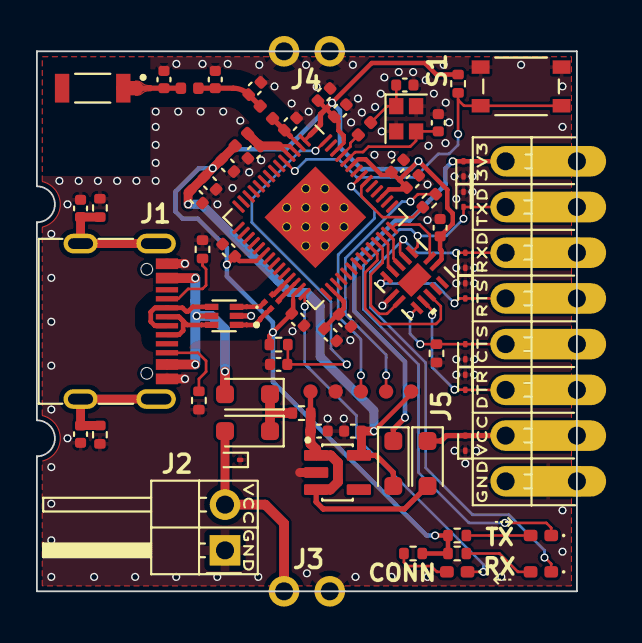
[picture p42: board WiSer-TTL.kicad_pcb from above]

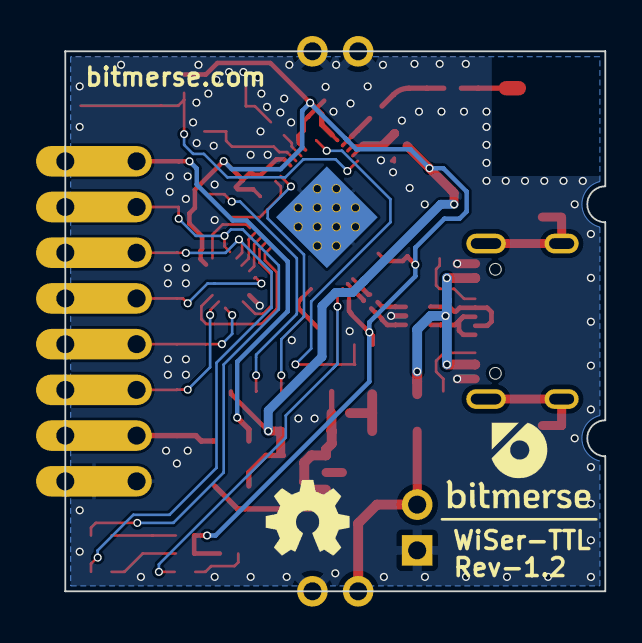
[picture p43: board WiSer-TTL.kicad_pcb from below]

Board: 4 copper layers, 30.0 x 30.0 mm, 75 parts (2 on the bottom side), 44 nets.

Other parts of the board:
G1, G2: LOGO

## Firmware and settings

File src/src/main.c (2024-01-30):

/**********************************************************************************
 * MIT License                                                                    *
 *                                                                                *
 * Copyright (c) 2024 Bitmerse LLP                                                *
 *                                                                                *
 * Permission is hereby granted, free of charge, to any person obtaining a copy   *
 * of this software and associated documentation files (the "Software"), to deal  *
 * in the Software without restriction, including without limitation the rights   *
 * to use, copy, modify, merge, publish, distribute, sublicense, and/or sell      *
 * copies of the Software, and to permit persons to whom the Software is          *
 * furnished to do so, subject to the following conditions:                       *
 *                                                                                *
 * The above copyright notice and this permission notice shall be included in all *
 * copies or substantial portions of the Software.                                *
 *                                                                                *
 * THE SOFTWARE IS PROVIDED "AS IS", WITHOUT WARRANTY OF ANY KIND, EXPRESS OR     *
 * IMPLIED, INCLUDING BUT NOT LIMITED TO THE WARRANTIES OF MERCHANTABILITY,       *
 * FITNESS FOR A PARTICULAR PURPOSE AND NONINFRINGEMENT. IN NO EVENT SHALL THE    *
 * AUTHORS OR COPYRIGHT HOLDERS BE LIABLE FOR ANY CLAIM, DAMAGES OR OTHER         *
 * LIABILITY, WHETHER IN AN ACTION OF CONTRACT, TORT OR OTHERWISE, ARISING FROM,  *
 * OUT OF OR IN CONNECTION WITH THE SOFTWARE OR THE USE OR OTHER DEALINGS IN THE  *
 * SOFTWARE.                                                                      *
 *********************************************************************************/
/**
 * @file main.c
 * @author Dhrumil Doshi
 * @date 25 January 2024
 * @brief main module inializes all application modules and runs application
 */

/**
 * @defgroup main application module
 * @brief Module for inializing all application modules and run application tasks
 * @{
 */


/**
 * @addtogroup main_include
 * @{
 */
#include "app.h"

/** @} */ // End of main_include group

/**
 * @addtogroup main_define
 * @{
 */

/** @} */ // End of main_define group


/**
 * @addtogroup main_global_funcs
 * @{
 */

/**
 * @brief initializes application modules and runs application
 *
 */
void app_main() {
    app_init();
}

/** @} */ // End of main_global_funcs group

/** @} */ // End of main module

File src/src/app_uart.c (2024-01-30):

/**********************************************************************************
 * MIT License                                                                    *
 *                                                                                *
 * Copyright (c) 2024 Bitmerse LLP                                                *
 *                                                                                *
 * Permission is hereby granted, free of charge, to any person obtaining a copy   *
 * of this software and associated documentation files (the "Software"), to deal  *
 * in the Software without restriction, including without limitation the rights   *
 * to use, copy, modify, merge, publish, distribute, sublicense, and/or sell      *
 * copies of the Software, and to permit persons to whom the Software is          *
 * furnished to do so, subject to the following conditions:                       *
 *                                                                                *
 * The above copyright notice and this permission notice shall be included in all *
 * copies or substantial portions of the Software.                                *
 *                                                                                *
 * THE SOFTWARE IS PROVIDED "AS IS", WITHOUT WARRANTY OF ANY KIND, EXPRESS OR     *
 * IMPLIED, INCLUDING BUT NOT LIMITED TO THE WARRANTIES OF MERCHANTABILITY,       *
 * FITNESS FOR A PARTICULAR PURPOSE AND NONINFRINGEMENT. IN NO EVENT SHALL THE    *
 * AUTHORS OR COPYRIGHT HOLDERS BE LIABLE FOR ANY CLAIM, DAMAGES OR OTHER         *
 * LIABILITY, WHETHER IN AN ACTION OF CONTRACT, TORT OR OTHERWISE, ARISING FROM,  *
 * OUT OF OR IN CONNECTION WITH THE SOFTWARE OR THE USE OR OTHER DEALINGS IN THE  *
 * SOFTWARE.                                                                      *
 *********************************************************************************/
/**
 * @file app_uart.c
 * @author Dhrumil Doshi
 * @date 25 January 2024
 * @brief UART communication implementation
 */

/**
 * @defgroup app_uart Application uart communication Module
 * @brief Module for managing application uart communication
 * @{
 */

/**
 * @addtogroup app_uart_include
 * @{
 */
#include <stdio.h>
#include <stdint.h>
#include <stdlib.h>
#include <string.h>
#include "freertos/FreeRTOS.h"
#include "freertos/task.h"
#include "freertos/queue.h"
#include "driver/uart.h"
#include "driver/gpio.h"
#include "sdkconfig.h"
#include "esp_intr_alloc.h"
#if CONFIG_IDF_TARGET_ESP32
    #include "esp32/rom/uart.h"
#elif CONFIG_IDF_TARGET_ESP32S2
    #include "esp32s2/rom/uart.h"
#endif
#include "config.h"
#include "commons.h"
#include "app_espnow.h"
#include "app_conn.h"
#include "app_uart.h"

/** @} */ // End of app_uart_include group
#if DEVICE_WISER_UART
/**
 * @addtogroup app_uart_define
 * @{
 */
/** @brief UART number */
#define APP_UART_NUM    UART_NUM_1
/** @brief UART baud rate */
#define APP_UART_BAUD_RATE  9600

// WiSer-UART
#define APP_UART_GPIO_RX  GPIO_NUM_37
#define APP_UART_GPIO_CTS GPIO_NUM_35
#define APP_UART_GPIO_TX  GPIO_NUM_38
#define APP_UART_GPIO_RTS GPIO_NUM_36
#define APP_UART_GPIO_DTR GPIO_NUM_34

/** @brief GPIO logic level to set */
#define APP_UART_GPIO_SET     1
/** @brief GPIO logic level to reset */
#define APP_UART_GPIO_RESET   0

/** @brief UART test configuration */
#define ECHO_TEST_TXD (CONFIG_EXAMPLE_UART_TXD)
#define ECHO_TEST_RXD (CONFIG_EXAMPLE_UART_RXD)
#define ECHO_TEST_RTS (UART_PIN_NO_CHANGE)
#define ECHO_TEST_CTS (UART_PIN_NO_CHANGE)

/** @brief UART buffer size */
#define BUF_SIZE (2048)

/** @} */ // End of app_uart_define group


/**
 * @addtogroup app_uart_static_vars
 * @{
 */
/** @brief Tag for logging */
static const char *TAG = "app_uart";

/** @brief Queue handle for UART */
static QueueHandle_t uart1_queue;

/** @} */ // End of app_uart_static_vars group

/**
 * @addtogroup app_uart_global_vars
 * @{
 */
uint8_t app_uart_hw_flow_status = APP_UART_HW_FLOW_DISABLE;

size_t total_uart_intr_received_len = 0;
size_t total_espnow_sent_len = 0;

/** @brief UART configuration structure */
uart_config_t uart_config = {
        .baud_rate = APP_UART_BAUD_RATE,
        .data_bits = UART_DATA_8_BITS,
        .parity    = UART_PARITY_DISABLE,
        .stop_bits = UART_STOP_BITS_1,
        .flow_ctrl = UART_HW_FLOWCTRL_DISABLE,
        .source_clk = UART_SCLK_APB,
    };

/** @} */ // End of app_uart_global_vars group

/**
 * @addtogroup app_uart_static_funcs
 * @{
 */

/** @brief Initialize UART low-level configuration */
static void app_uart_ll_init(void);

/**
 * @brief Initialize uart pins and enable RTS/CTS hardware flow control.
 * 
 */
static void app_uart_hw_flow_enable(void);

/**
 * @brief Initialize uart pins and disable RTS/CTS hardware flow control.
 * 
 */
static void app_uart_hw_flow_disable(void);

/** @brief Initialize DTR pin for UART communication */
static void app_uart_dtr_init(void);

/** @brief Task to handle UART events */
static void app_uart_event_task(void *pvParameters);

/**
 * @brief initialize app UART tasks.
 * 
 * @return error code
 */
static int app_uart_tasks_init(void);

/** @} */ // End of app_espnow_static_funcs group

/**
 * @addtogroup app_uart_static_funcs
 * @{
 */

/**
 * @brief Initialize UART.
 * 
 */
static void app_uart_ll_init(void)
{
    int intr_alloc_flags = 0;

    app_espnow_send_timeout = (uint32_t)((APP_ESPNOW_SEND_DATA_SIZE*8*1000)/uart_config.baud_rate) + (uint32_t)(1000/uart_config.baud_rate) + 20;
    ESP_LOGE(TAG, "app_espnow_send_timeout: %lu", app_espnow_send_timeout);
    gpio_pullup_dis(APP_UART_GPIO_CTS);

    intr_alloc_flags = ESP_INTR_FLAG_IRAM;
    
    ESP_ERROR_CHECK(uart_driver_install(APP_UART_NUM, BUF_SIZE*8, BUF_SIZE, 200, &uart1_queue, intr_alloc_flags));
    uart_config.rx_flow_ctrl_thresh = UART_FIFO_LEN - 1;
    ESP_ERROR_CHECK(uart_param_config(APP_UART_NUM, &uart_config));
    
    app_uart_hw_flow_disable();
}


/**
 * @brief Initialize uart pins and enable RTS/CTS hardware flow control.
 * 
 */
static void app_uart_hw_flow_enable(void) 
{
    //for uart with flow control
    ESP_ERROR_CHECK(uart_set_pin(APP_UART_NUM, APP_UART_GPIO_TX, APP_UART_GPIO_RX, APP_UART_GPIO_RTS, APP_UART_GPIO_CTS));

    gpio_pullup_en(APP_UART_GPIO_RTS);
    gpio_set_pull_mode(APP_UART_GPIO_RTS, GPIO_PULLUP_ONLY);
    gpio_pullup_en(APP_UART_GPIO_CTS);
    gpio_set_pull_mode(APP_UART_GPIO_CTS, GPIO_PULLUP_ONLY);
}
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

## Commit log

2024-01-30 add hardware design files
    [WiSer-TTL.kicad_pcb, WiSer-TTL.kicad_sch, WiSer-USB.kicad_pcb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]
2024-05-22 Update hardware design files
    [WiSer-TTL.kicad_pcb, WiSer-TTL.kicad_sch, WiSer-USB.kicad_pcb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]

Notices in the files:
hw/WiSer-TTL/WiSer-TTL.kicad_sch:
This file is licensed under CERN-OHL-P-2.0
